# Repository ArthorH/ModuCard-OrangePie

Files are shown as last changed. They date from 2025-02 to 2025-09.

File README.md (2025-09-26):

# ModuCard System Orange PI 5 pro adapter
obraz

## Project Status: **Ongoing**  
### REV C
**Design** ⏳ — **Fabrication** ⏳ — **Assembly** ⏳ — **Bringup** ⏳ — **Testing** ⏳
### REV B
**Design** ✅ — **Fabrication** ✅ — **Assembly** ✅ — **Bringup** ✅ — **Testing** ⛔ 
Failed: https://github.com/ArthorH/ModuCard-OrangePie/issues/6
### REV A
**Design** ✅ — **Fabrication** ✅ — **Assembly** ✅ — **Bringup** ✅ — **Testing** ✅ 
## Key technologies:
&nbsp;&nbsp;&nbsp;&nbsp; &nbsp;&nbsp;&nbsp;&nbsp; &nbsp;&nbsp;&nbsp;&nbsp;
# Features

- 5V 8A psu for Orange PI
- Embedded USB audo interface
- Embedded USB CAN adapter
- External Fan controller
- UART debug interface
  
# Block Diagram
&nbsp;&nbsp;&nbsp;&nbsp;

# Manufactured board


# Moducard OrangePie in Zwentendorf Austria!
AMSModuCard

### Check out other projects

Orange Pie ->  https://github.com/ArthorH/ModuCard-OrangePie

ModuCard Base module -> https://github.com/ArthorH/ModuCard-base-module

ModuCard Backplane -> https://github.com/ArthorH/ModuCard-backplane

ezgif-5062213efaebb7

# Author
Artem Horiunov
# License 
To be added

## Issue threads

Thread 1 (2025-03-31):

Orange hardware issues

X-Lemon-X, 2025-03-31:
- Dodać reset do RPI do  STM od cana i  audio DACa.
- STM brak opużnienia dla właczenia can transceivers ze względu an pin CAN_RX/BOOT0 co powoduje w przejście do  DFU.  takie coć trzeba dodać:
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

Poza tym reszta działa

ArthorH, 2025-05-15:
Do tego układu należy dodać możliwość resetu jest jest triggerowana linia restu stm !!!!

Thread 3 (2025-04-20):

Create layout for fixed schematic

ArthorH, 2025-04-20:

Closed 2025-05-15.

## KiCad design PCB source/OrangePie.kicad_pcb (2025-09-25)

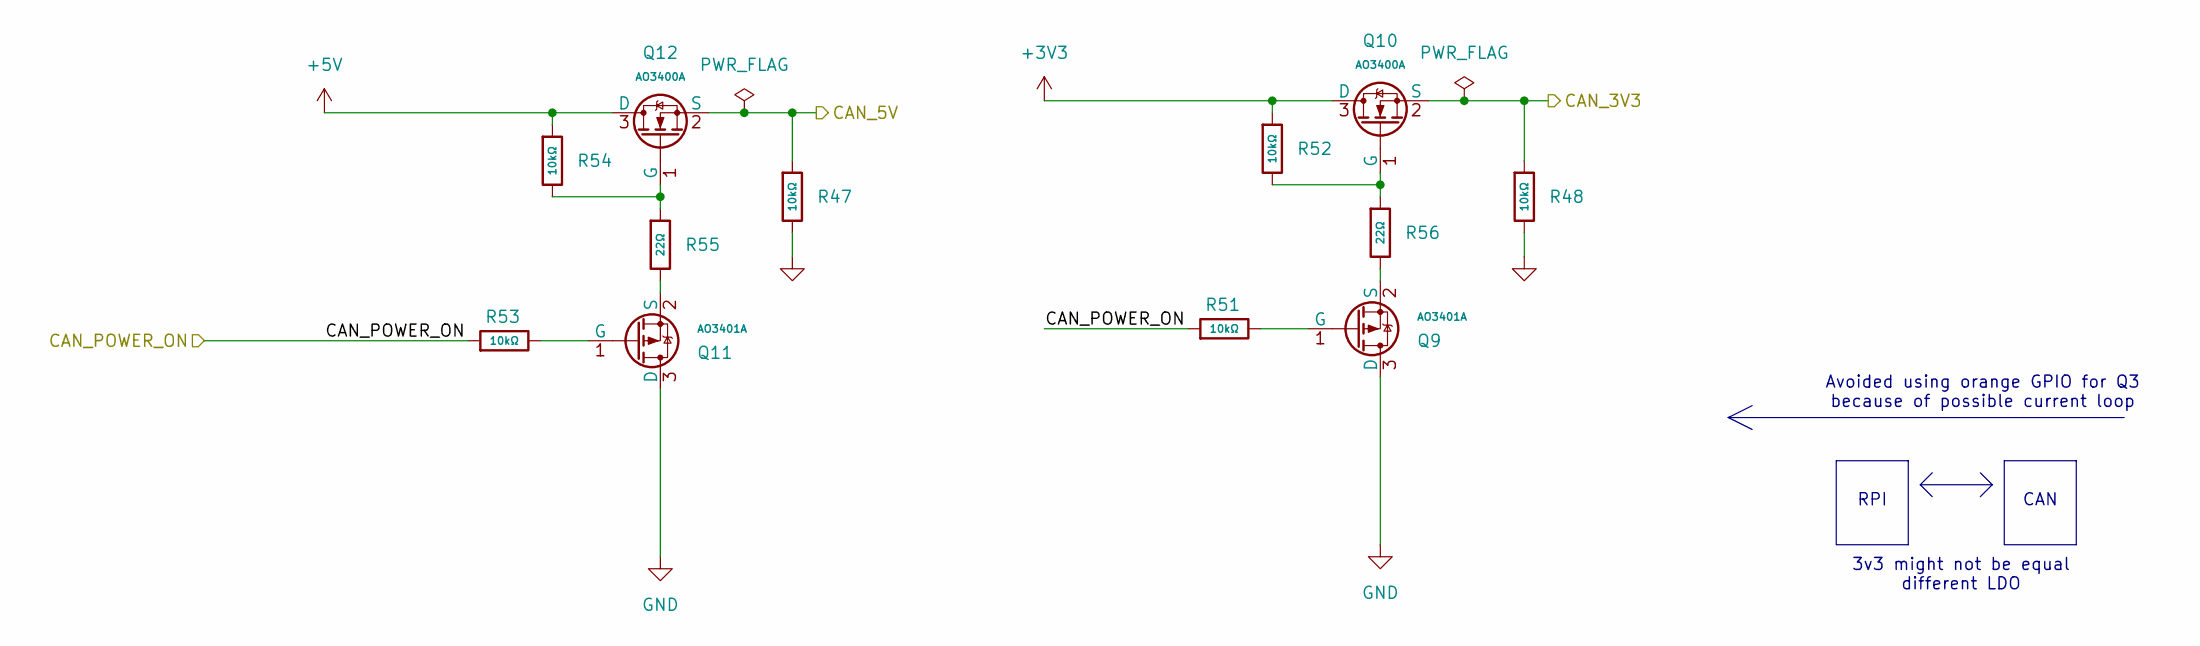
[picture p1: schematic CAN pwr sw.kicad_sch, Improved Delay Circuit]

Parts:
Q9, Q11: AO3401A; Q_SOT-23; Part AO3401A; LCSC C15127
Q10, Q12: AO3400A; Q_SOT-23; Part AO3400A; LCSC C20917
R47, R48, R51, R52, R53, R54: 10kΩ; R_0402; Overload Voltage (Max) 50V; Tolerance ±1%; Part 0402WGF1002TCE; LCSC C25744
R55, R56: 22Ω; R_0402; Overload Voltage (Max) 50V; Tolerance ±1%; Part 0402WGF220JTCE; LCSC C25092

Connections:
+3V3: Q10.3 (D), R52.1; also elsewhere on the board
+5V: Q12.3 (D), R54.1; also elsewhere on the board
/CAN pwr sw/CAN_3V3: Q10.2 (S), R48.1; also elsewhere on the board
/CAN pwr sw/CAN_5V: Q12.2 (S), R47.1; also elsewhere on the board
/CAN pwr sw/CAN_POWER_ON: R51.1, R53.1; also elsewhere on the board
GND: Q9.3 (D), Q11.3 (D), R47.2, R48.2; also elsewhere on the board
unnamed: Q9.1 (G), R51.2
unnamed: Q9.2 (S), R56.2
unnamed: Q10.1 (G), R52.2, R56.1
unnamed: Q11.1 (G), R53.2
unnamed: Q11.2 (S), R55.2
unnamed: Q12.1 (G), R54.2, R55.1

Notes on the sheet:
Avoided using orange GPIO for Q3 because of possible current loop
CAN
RPI
3v3 might not be equal different LDO

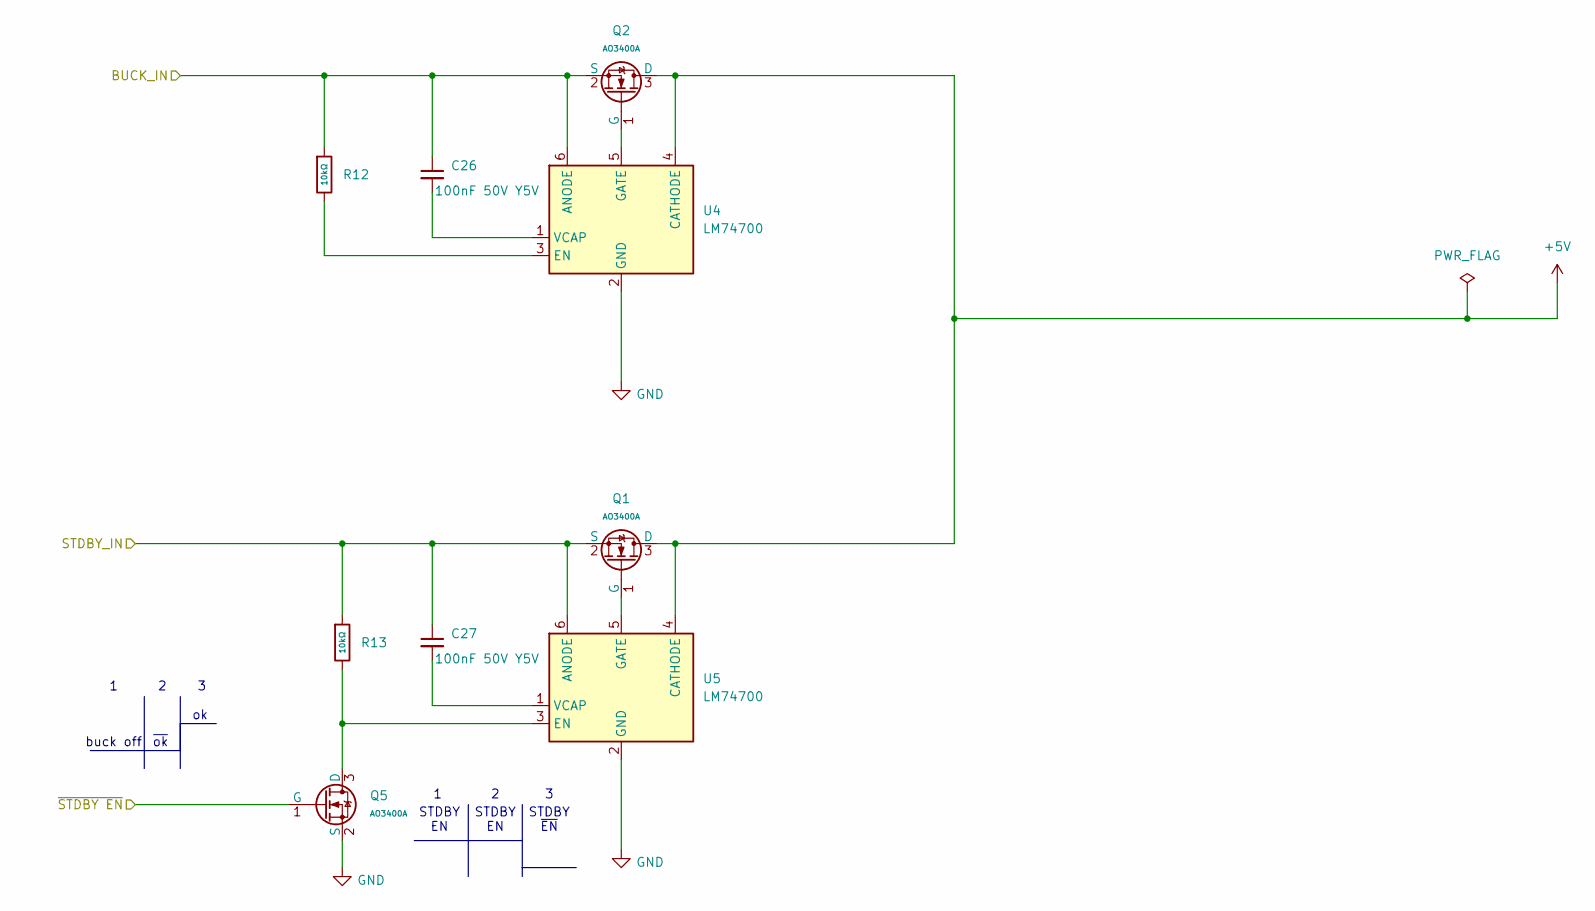
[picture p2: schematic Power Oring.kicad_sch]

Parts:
C26, C27: 100nF 50V Y5V; C_0402_1005Metric
Q1, Q2, Q5: AO3400A; Q_SOT-23; Part AO3400A; LCSC C20917
R12, R13: 10kΩ; R_0402; Overload Voltage (Max) 50V; Tolerance ±1%; Part 0402WGF1002TCE; LCSC C25744
U4, U5: LM74700; SOT-23-6

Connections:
+5V: Q1.3 (D), Q2.3 (D), U4.4 (CATHODE), U5.4 (CATHODE); also elsewhere on the board
/5v buck/BUCK_OUT: C26.1, Q2.2 (S), R12.1, U4.6 (ANODE); also elsewhere on the board
/5v buck/Pgood: Q5.1 (G); also elsewhere on the board
/DIN41612 connector/5v_STDBY: C27.1, Q1.2 (S), R13.1, U5.6 (ANODE); also elsewhere on the board
GND: Q5.2 (S), U4.2 (GND), U5.2 (GND); also elsewhere on the board
unnamed: Q1.1 (G), U5.5 (GATE)
unnamed: Q2.1 (G), U4.5 (GATE)
unnamed: Q5.3 (D), R13.2, U5.3 (EN)
unnamed: R12.2, U4.3 (EN)
unnamed: C26.2, U4.1 (VCAP)
unnamed: C27.2, U5.1 (VCAP)

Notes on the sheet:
buck off
~{ok}
STDBY EN
STDBY ~{EN}

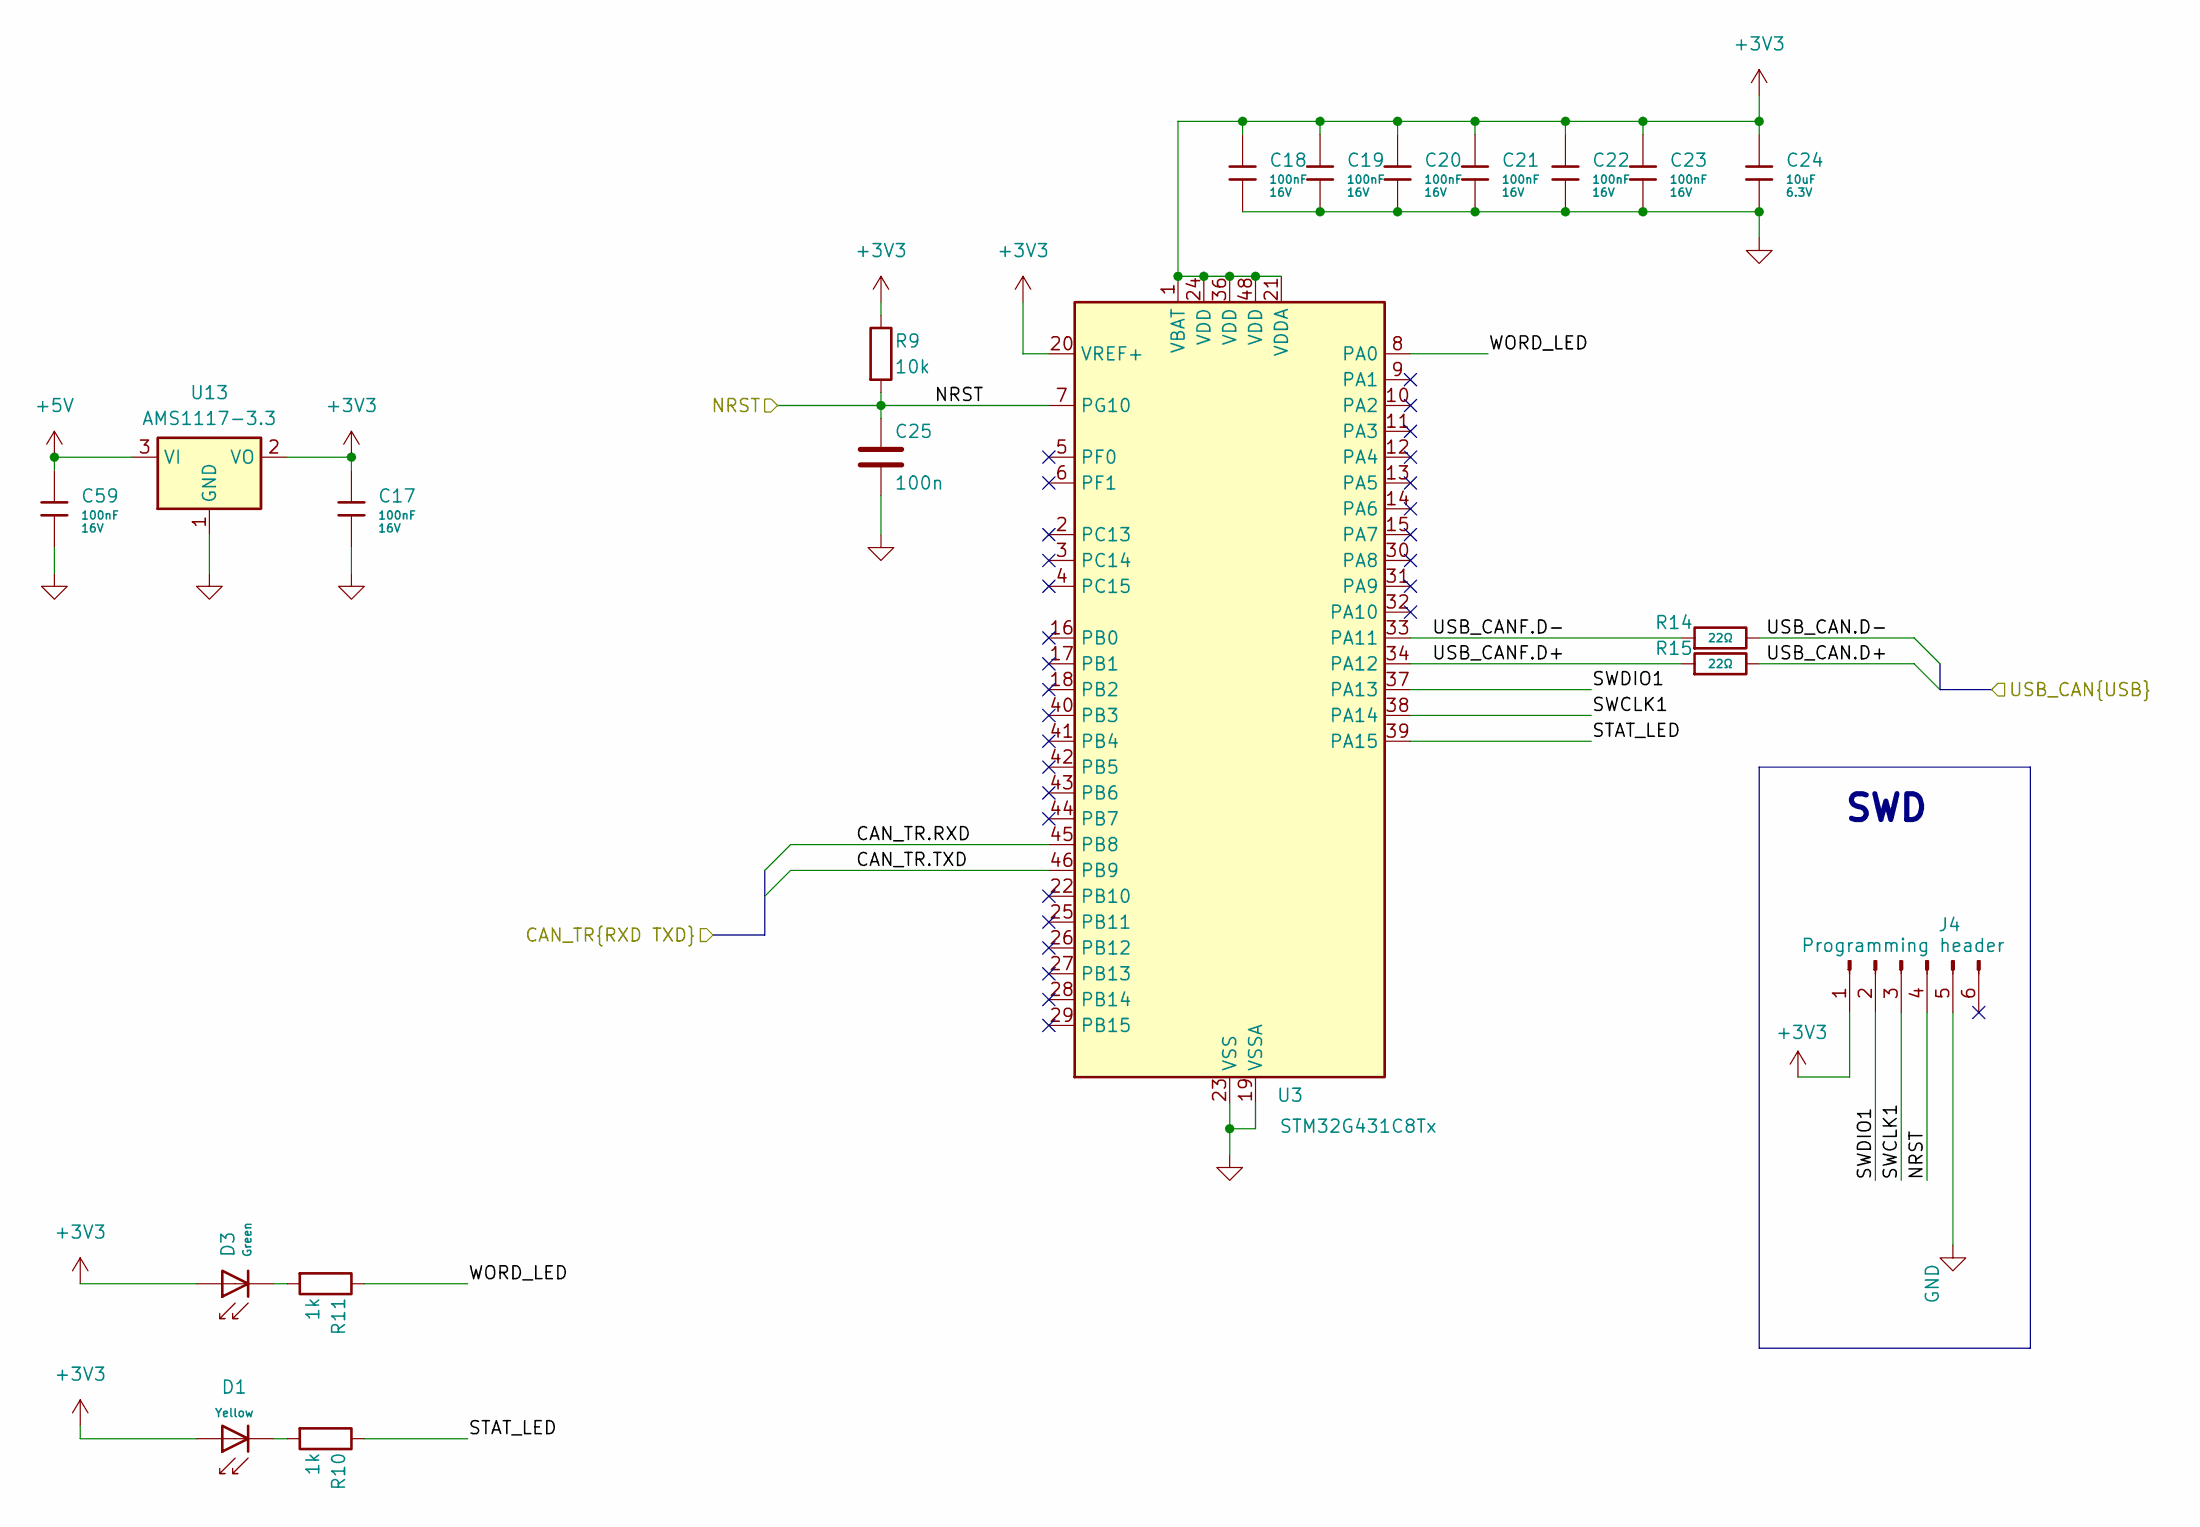
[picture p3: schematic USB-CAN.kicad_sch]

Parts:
C17, C18, C19, C20, C21, C22, C23, C59: 100nF; C_0402; Voltage Rated 16V; Tolerance ±10%; Part CL05B104KO5NNNC; LCSC C1525
C24: 10uF; C_0402; Voltage Rated 6.3V; Tolerance ±20%; Part CL05A106MQ5NUNC; LCSC C15525
C25: 100n; C_0402_1005Metric
D1: Yellow; D_0603; Part 19-213/Y2C-CQ2R2L/3T(CY); LCSC C72038
D3: Green; D_0603; Part 19-217/GHC-YR1S2/6T; LCSC C2986059
J4: Programming header; PinHeader_1x06_P1.27mm_Vertical
R9: 10k; R_0402_1005Metric
R10, R11: 1k; R_0402_1005Metric
R14, R15: 22Ω; R_0402; Overload Voltage (Max) 50V; Tolerance ±1%; Part 0402WGF220JTCE; LCSC C25092
U3: STM32G431C8Tx; LQFP-48_7x7mm_P0.5mm
U13: AMS1117-3.3; SOT-223-3_TabPin2

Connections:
+3V3: C17.1, C18.1, C19.1, C20.1, C21.1, C22.1, C23.1, C24.1, D1.2, D3.2, J4.1, R9.1, U3.1 (VBAT), U3.20 (VREF+), U3.21 (VDDA), U3.24 (VDD), U3.36 (VDD), U3.48 (VDD), U13.2 (VO); also elsewhere on the board
+5V: C59.1, U13.3 (VI); also elsewhere on the board
/Can Transiver1/CAN_TR.RXD: U3.45 (PB8); also elsewhere on the board
/Can Transiver1/CAN_TR.TXD: U3.46 (PB9); also elsewhere on the board
/USB HUB/USB_CAN.D+: R15.2; also elsewhere on the board
/USB HUB/USB_CAN.D-: R14.2; also elsewhere on the board
/USB-CAN/NRST: C25.1, J4.4, R9.2, U3.7 (PG10); also elsewhere on the board
/USB-CAN/STAT_LED: R10.1, U3.39 (PA15)
/USB-CAN/SWCLK1: J4.3, U3.38 (PA14)
/USB-CAN/SWDIO1: J4.2, U3.37 (PA13)
/USB-CAN/USB_CANF.D+: R15.1, U3.34 (PA12)
/USB-CAN/USB_CANF.D-: R14.1, U3.33 (PA11)
/USB-CAN/WORD_LED: R11.1, U3.8 (PA0)
GND: C17.2, C18.2, C19.2, C20.2, C21.2, C22.2, C23.2, C24.2, C25.2, C59.2, J4.5, U3.19 (VSSA), U3.23 (VSS), U3.35 (VSS), U3.47 (VSS), U13.1 (GND); also elsewhere on the board
unnamed: D1.1, R10.2
unnamed: D3.1, R11.2

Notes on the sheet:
SWD

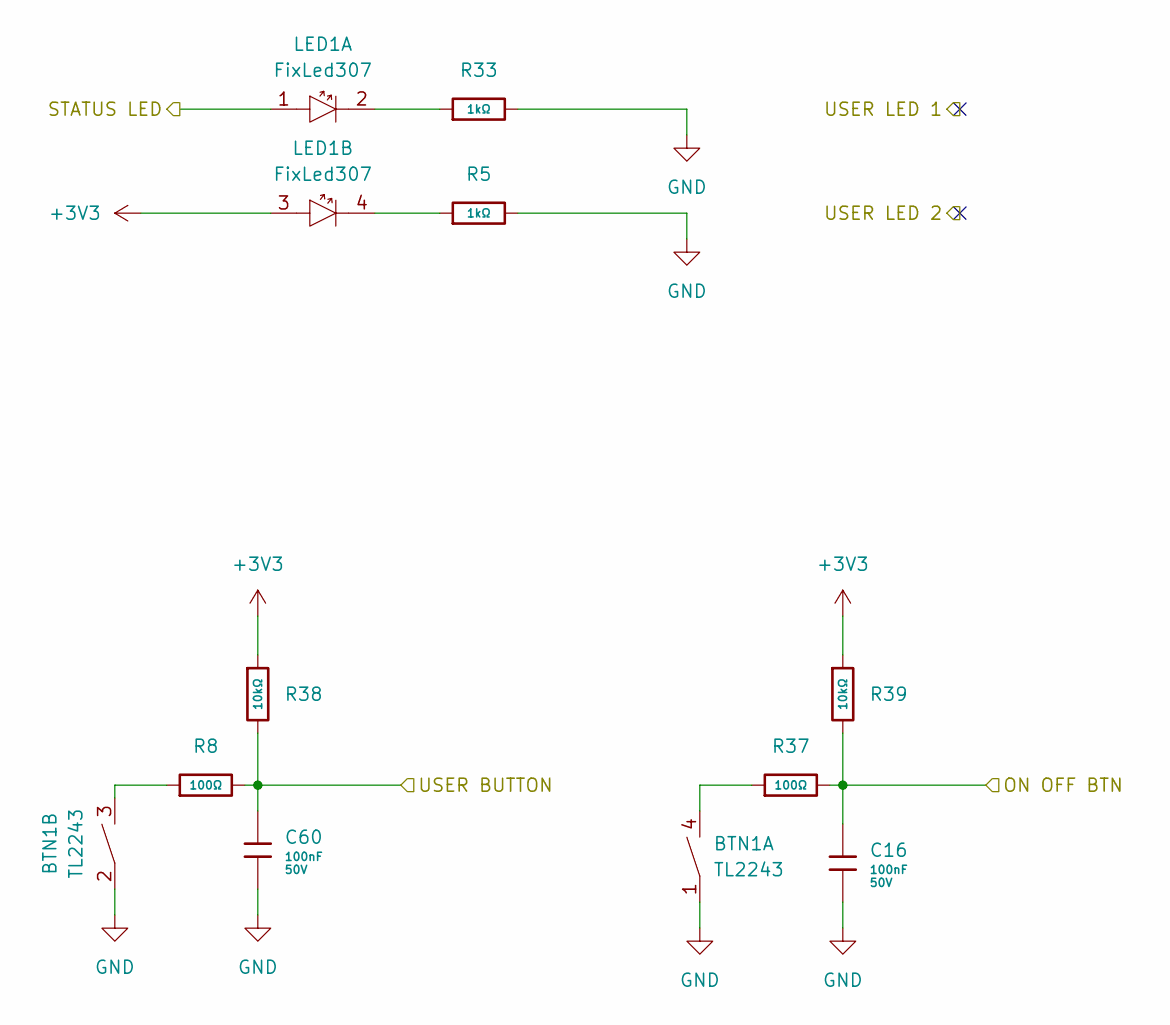
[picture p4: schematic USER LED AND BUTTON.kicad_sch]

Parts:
BTN1: TL2243
C16, C60: 100nF; C_0402; Voltage Rated 50V; Tolerance ±10%; Part CL05B104KB54PNC; LCSC C307331
LED1: FixLed307
R5, R33: 1kΩ; R_0402; Overload Voltage (Max) 50V; Tolerance ±1%; Part 0402WGF1001TCE; LCSC C11702
R8, R37: 100Ω; R_0402; Overload Voltage (Max) 50V; Tolerance ±1%; Part 0402WGF1000TCE; LCSC C25076
R38, R39: 10kΩ; R_0402; Overload Voltage (Max) 50V; Tolerance ±1%; Part 0402WGF1002TCE; LCSC C25744

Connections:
+3V3: LED1.3, R38.1, R39.1; also elsewhere on the board
/OrangePi 5 pro Header/ON OFF BTN: C16.1, R37.2, R39.2; also elsewhere on the board
/OrangePi 5 pro Header/STATUS LED: LED1.1; also elsewhere on the board
/OrangePi 5 pro Header/USER BUTTON: C60.1, R8.2, R38.2; also elsewhere on the board
GND: BTN1.1, BTN1.2, C16.2, C60.2, R5.2, R33.2; also elsewhere on the board
unnamed: BTN1.3, R8.1
unnamed: BTN1.4, R37.1
unnamed: LED1.2, R33.1
unnamed: LED1.4, R5.1

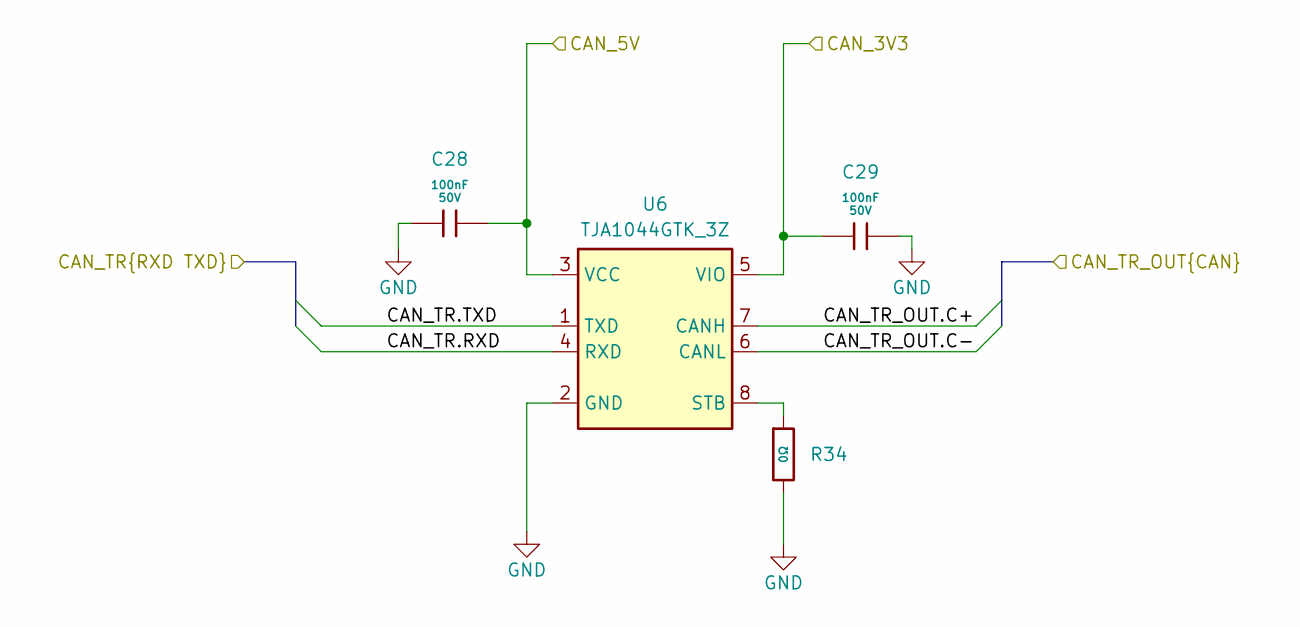
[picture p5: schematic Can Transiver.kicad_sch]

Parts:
C28, C29: 100nF; C_0402; Voltage Rated 50V; Tolerance ±10%; Part CL05B104KB54PNC; LCSC C307331
R34: 0Ω; R_0402; Overload Voltage (Max) 50V; Tolerance ±1%; Part 0402WGF0000TCE; LCSC C17168
U6: TJA1044GTK_3Z; HVSON-8-1EP_3x3mm_P0.65mm_EP1.6x2.4mm; Manufacturer_Part_Number TJA1044GTK/3Z

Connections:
/CAN pwr sw/CAN_3V3: C29.1, U6.5 (VIO); also elsewhere on the board
/CAN pwr sw/CAN_5V: C28.2, U6.3 (VCC); also elsewhere on the board
/Can Transiver/CAN_TR.RXD: U6.4 (RXD); also elsewhere on the board
/Can Transiver/CAN_TR.TXD: U6.1 (TXD); also elsewhere on the board
/Can Transiver/CAN_TR_OUT.C+: U6.7 (CANH); also elsewhere on the board
/Can Transiver/CAN_TR_OUT.C-: U6.6 (CANL); also elsewhere on the board
GND: C28.1, C29.2, R34.2, U6.2 (GND), U6.9 (EP); also elsewhere on the board
unnamed: R34.1, U6.8 (STB)

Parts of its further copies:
C30, C31: 100nF; C_0402; Voltage Rated 50V; Tolerance ±10%; Part CL05B104KB54PNC; LCSC C307331
R35: 0Ω; R_0402; Overload Voltage (Max) 50V; Tolerance ±1%; Part 0402WGF0000TCE; LCSC C17168
U7: TJA1044GTK_3Z; HVSON-8-1EP_3x3mm_P0.65mm_EP1.6x2.4mm; Manufacturer_Part_Number TJA1044GTK/3Z

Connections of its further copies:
/CAN pwr sw/CAN_3V3: C31.1, U7.5 (VIO); also elsewhere on the board
/CAN pwr sw/CAN_5V: C30.2, U7.3 (VCC); also elsewhere on the board
/Can Transiver1/CAN_TR.RXD: U7.4 (RXD); also elsewhere on the board
/Can Transiver1/CAN_TR.TXD: U7.1 (TXD); also elsewhere on the board
/Can Transiver1/CAN_TR_OUT.C+: U7.7 (CANH); also elsewhere on the board
/Can Transiver1/CAN_TR_OUT.C-: U7.6 (CANL); also elsewhere on the board
GND: C30.1, C31.2, R35.2, U7.2 (GND), U7.9 (EP); also elsewhere on the board
unnamed: R35.1, U7.8 (STB)

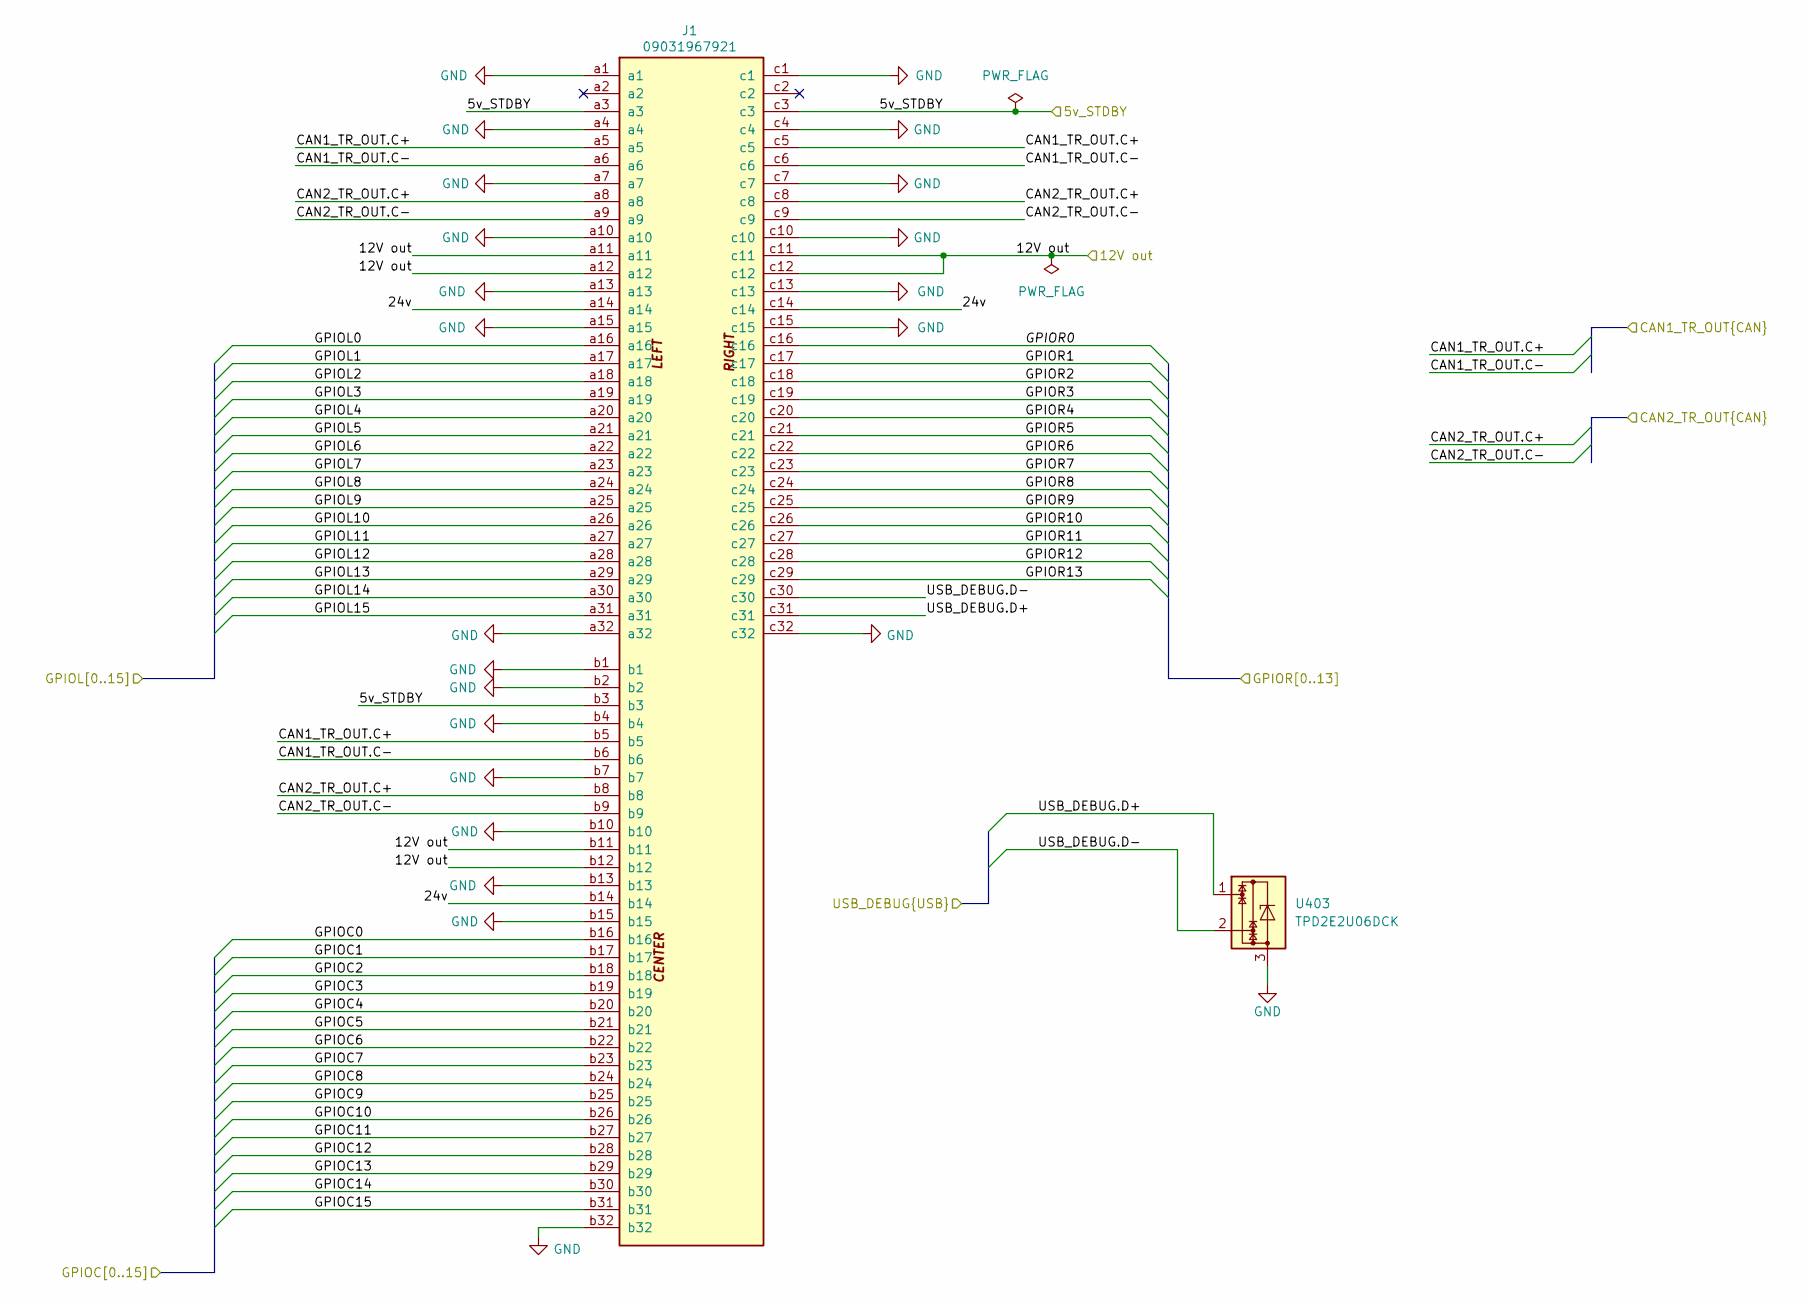
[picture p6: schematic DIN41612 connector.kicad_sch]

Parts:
J1: 09031967921; DIN41612_R_3x32_Female_Horizontal_THT; PARTREV D
U403: TPD2E2U06DCK; SOT-323_SC-70

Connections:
/5v buck/V_{IN}: J1.a11, J1.a12, J1.b11, J1.b12, J1.c11, J1.c12; also elsewhere on the board
/Can Transiver1/CAN_TR_OUT.C+: J1.a8, J1.b8, J1.c8; also elsewhere on the board
/Can Transiver1/CAN_TR_OUT.C-: J1.a9, J1.b9, J1.c9; also elsewhere on the board
/Can Transiver/CAN_TR_OUT.C+: J1.a5, J1.b5, J1.c5; also elsewhere on the board
/Can Transiver/CAN_TR_OUT.C-: J1.a6, J1.b6, J1.c6; also elsewhere on the board
/DIN41612 connector/5v_STDBY: J1.a3, J1.b3, J1.c3; also elsewhere on the board
/DIN41612 connector/24v: J1.a14, J1.b14, J1.c14
/DIN41612 connector/GPIOC0: J1.b16
/DIN41612 connector/GPIOC1: J1.b17
/DIN41612 connector/GPIOC2: J1.b18
/DIN41612 connector/GPIOC3: J1.b19
/DIN41612 connector/GPIOC4: J1.b20
/DIN41612 connector/GPIOC5: J1.b21
/DIN41612 connector/GPIOC6: J1.b22
/DIN41612 connector/GPIOC7: J1.b23
/DIN41612 connector/GPIOC8: J1.b24
/DIN41612 connector/GPIOC9: J1.b25
/DIN41612 connector/GPIOC10: J1.b26
/DIN41612 connector/GPIOC11: J1.b27
/DIN41612 connector/GPIOC12: J1.b28
/DIN41612 connector/GPIOC13: J1.b29
/DIN41612 connector/GPIOC14: J1.b30
/DIN41612 connector/GPIOC15: J1.b31
/DIN41612 connector/GPIOL0: J1.a16
/DIN41612 connector/GPIOL1: J1.a17
/DIN41612 connector/GPIOL2: J1.a18
/DIN41612 connector/GPIOL3: J1.a19
/DIN41612 connector/GPIOL4: J1.a20
/DIN41612 connector/GPIOL5: J1.a21
/DIN41612 connector/GPIOL6: J1.a22
/DIN41612 connector/GPIOL7: J1.a23
/DIN41612 connector/GPIOL8: J1.a24
/DIN41612 connector/GPIOL9: J1.a25
/DIN41612 connector/GPIOL10: J1.a26
/DIN41612 connector/GPIOL11: J1.a27
/DIN41612 connector/GPIOL12: J1.a28
/DIN41612 connector/GPIOL13: J1.a29
/DIN41612 connector/GPIOL14: J1.a30
/DIN41612 connector/GPIOL15: J1.a31
/DIN41612 connector/GPIOR0: J1.c16
/DIN41612 connector/GPIOR1: J1.c17
/DIN41612 connector/GPIOR2: J1.c18
/DIN41612 connector/GPIOR3: J1.c19
/DIN41612 connector/GPIOR4: J1.c20
/DIN41612 connector/GPIOR5: J1.c21
/DIN41612 connector/GPIOR6: J1.c22
/DIN41612 connector/GPIOR7: J1.c23
/DIN41612 connector/GPIOR8: J1.c24
/DIN41612 connector/GPIOR9: J1.c25
/DIN41612 connector/GPIOR10: J1.c26
/DIN41612 connector/GPIOR11: J1.c27
/DIN41612 connector/GPIOR12: J1.c28
/DIN41612 connector/GPIOR13: J1.c29
/DIN41612 connector/USB_DEBUG.D+: J1.c31, U403.1; also elsewhere on the board
/DIN41612 connector/USB_DEBUG.D-: J1.c30, U403.2; also elsewhere on the board
GND: J1.a1, J1.a4, J1.a7, J1.a10, J1.a13, J1.a15, J1.a32, J1.b1, J1.b2, J1.b4, J1.b7, J1.b10, J1.b13, J1.b15, J1.b32, J1.c1, J1.c4, J1.c7, J1.c10, J1.c13, J1.c15, J1.c32, U403.3; also elsewhere on the board

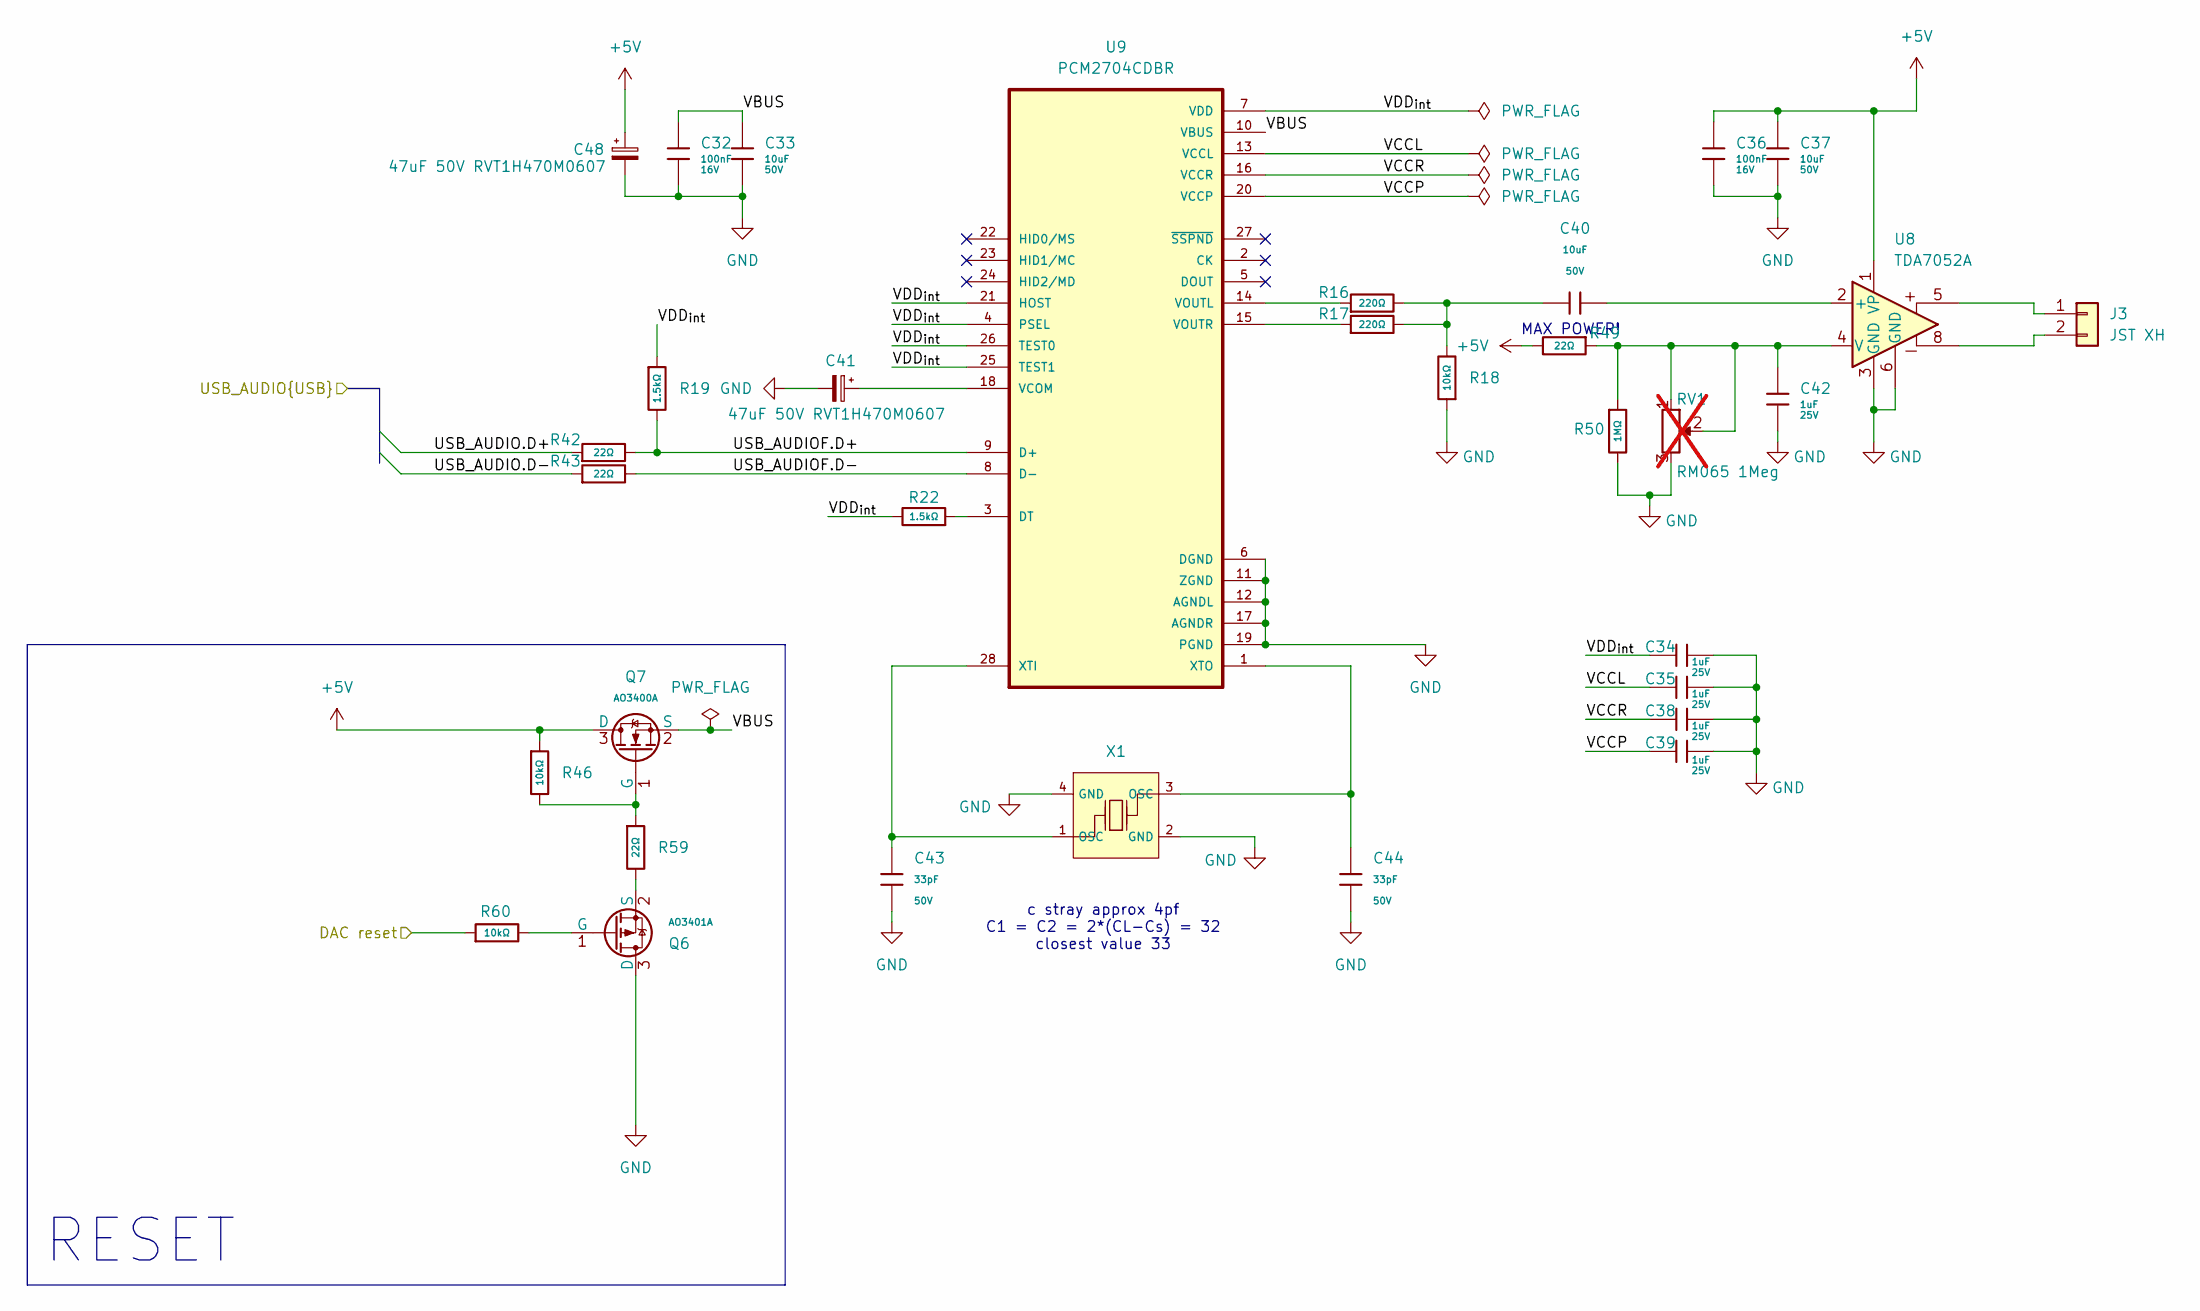
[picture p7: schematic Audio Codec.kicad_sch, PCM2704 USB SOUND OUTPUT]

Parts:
C32, C36: 100nF; C_0402; Voltage Rated 16V; Tolerance ±10%; Part CL05B104KO5NNNC; LCSC C1525
C33, C37, C40: 10uF; C_0805; Voltage Rated 50V; Tolerance ±10%; Part GRM21BR61H106KE43L; LCSC C440198
C34, C35, C38, C39, C42: 1uF; C_0402; Voltage Rated 25V; Tolerance ±10%; Part CL05A105KA5NQNC; LCSC C52923
C41, C48: 47uF 50V RVT1H470M0607; CP_Elec_6.3x7.7
C43, C44: 33pF; C_0402; Voltage Rated 50V; Tolerance ±5%; Part 0402CG330J500NT; LCSC C1562
J3: JST XH; JST_XH_B2B-XH-AM_1x02_P2.50mm_Vertical
Q6: AO3401A; Q_SOT-23; Part AO3401A; LCSC C15127
Q7: AO3400A; Q_SOT-23; Part AO3400A; LCSC C20917
R16, R17: 220Ω; R_0402; Overload Voltage (Max) 50V; Tolerance ±1%; Part 0402WGF2200TCE; LCSC C25091
R18, R46, R60: 10kΩ; R_0402; Overload Voltage (Max) 50V; Tolerance ±1%; Part 0402WGF1002TCE; LCSC C25744
R19, R22: 1.5kΩ; R_0402; Overload Voltage (Max) 50V; Tolerance ±1%; Part 0402WGF1501TCE; LCSC C25867
R42, R43, R49, R59: 22Ω; R_0402; Overload Voltage (Max) 50V; Tolerance ±1%; Part 0402WGF220JTCE; LCSC C25092
R50: 1MΩ; R_0402; Overload Voltage (Max) 50V; Tolerance ±1%; Part 0402WGF1004TCE; LCSC C26083
RV1: RM065 1Meg; Potentiometer_Runtron_RM-065_Vertical; not fitted
U8: TDA7052A; SO-8_3.9x4.9mm_P1.27mm
U9: PCM2704CDBR; SSOP-28_5.3x10.2mm_P0.65mm
X1: X322512MSB4SI; CRYSTAL-SMD_4P-L3.2-W2.5-BL; Frequency Tolerance ±10ppm; Part X322512MSB4SI; LCSC C9002

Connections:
+5V: C36.1, C37.2, C48.1, Q7.3 (D), R46.1, R49.2, U8.1 (VP); also elsewhere on the board
/Audio Codec/DAC reset: R60.1; also elsewhere on the board
/Audio Codec/USB_AUDIO.D+: R42.1; also elsewhere on the board
/Audio Codec/USB_AUDIO.D-: R43.1; also elsewhere on the board
/Audio Codec/USB_AUDIOF.D+: R19.2, R42.2, U9.9 (D+)
/Audio Codec/USB_AUDIOF.D-: R43.2, U9.8 (D-)
/Audio Codec/VBUS: C32.1, C33.2, Q7.2 (S), U9.10 (VBUS)
/Audio Codec/VCCL: C35.1, U9.13 (VCCL)
/Audio Codec/VCCP: C39.1, U9.20 (VCCP)
/Audio Codec/VCCR: C38.1, U9.16 (VCCR)
/Audio Codec/VDD_{int}: C34.1, R19.1, R22.2, U9.4 (PSEL), U9.7 (VDD), U9.21 (HOST), U9.25 (TEST1), U9.26 (TEST0)
GND: C32.2, C33.1, C34.2, C35.2, C36.2, C37.1, C38.2, C39.2, C41.2, C42.2, C43.2, C44.2, C48.2, Q6.3 (D), R18.1, R50.2, RV1.3, U8.3 (GND), U8.6 (GND), U9.6 (DGND), U9.11 (ZGND), U9.12 (AGNDL), U9.17 (AGNDR), U9.19 (PGND), X1.2 (GND), X1.4 (GND); also elsewhere on the board
unnamed: C40.2, R16.2, R17.2, R18.2
unnamed: J3.1, U8.5
unnamed: J3.2, U8.8
unnamed: Q6.1 (G), R60.2
unnamed: Q6.2 (S), R59.2
unnamed: Q7.1 (G), R46.2, R59.1
unnamed: C40.1, U8.2 (+)
unnamed: C42.1, R49.1, R50.1, RV1.1, RV1.2, U8.4 (V)
unnamed: R22.1, U9.3 (DT)
unnamed: C41.1, U9.18 (VCOM)
unnamed: R16.1, U9.14 (VOUTL)
unnamed: R17.1, U9.15 (VOUTR)
unnamed: C43.1, U9.28 (XTI), X1.1 (OSC)
unnamed: C44.1, U9.1 (XTO), X1.3 (OSC)

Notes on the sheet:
RESET
MAX POWER!
c stray approx 4pf C1 = C2 = 2*(CL-Cs) = 32 closest value 33

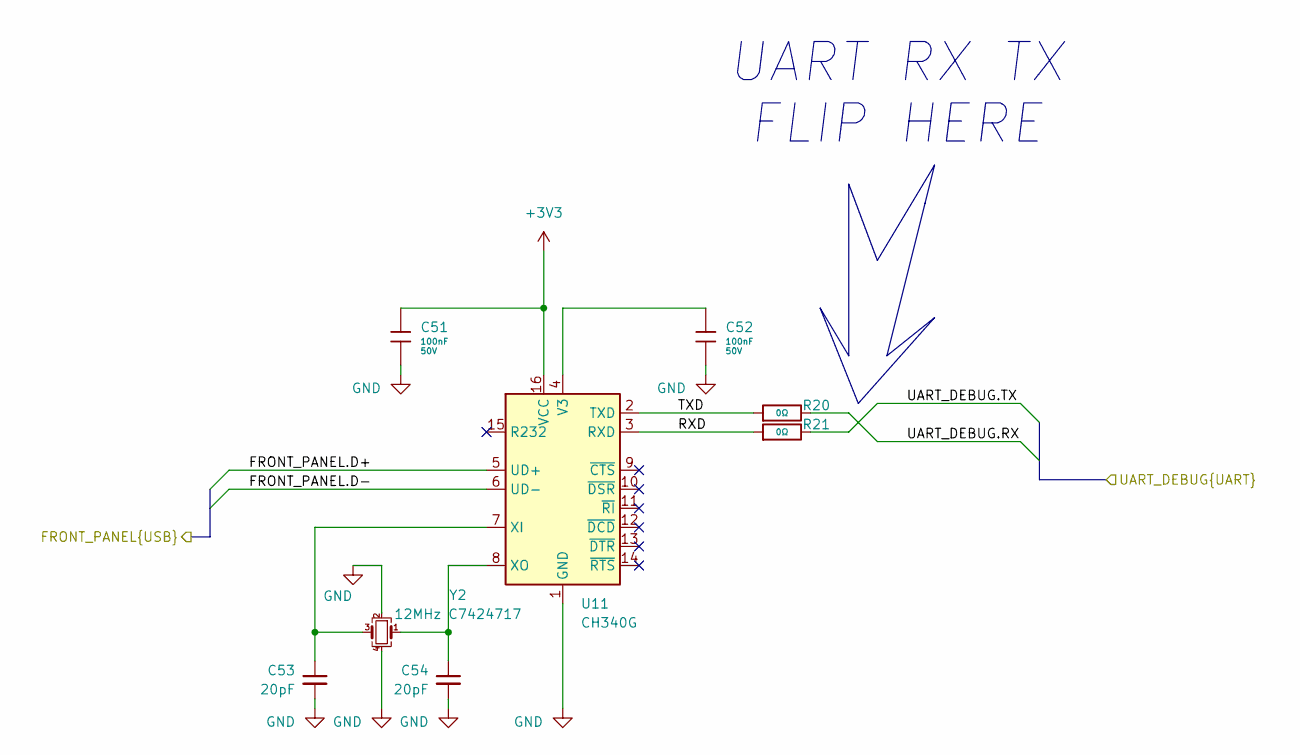
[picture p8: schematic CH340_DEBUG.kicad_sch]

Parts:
C51, C52: 100nF; C_0402; Voltage Rated 50V; Tolerance ±10%; Part CL05B104KB54PNC; LCSC C307331
C53, C54: 20pF; C_0402_1005Metric
R20, R21: 0Ω; R_0402; Overload Voltage (Max) 50V; Tolerance ±1%; Part 0402WGF0000TCE; LCSC C17168
U11: CH340G; SOIC-16_3.9x9.9mm_P1.27mm
Y2: 12MHz C7424717; Crystal_SMD_3225-4Pin_3.2x2.5mm

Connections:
+3V3: C51.1, U11.16 (VCC); also elsewhere on the board
/CH340_DEBUG/FRONT_PANEL.D+: U11.5 (UD+); also elsewhere on the board
/CH340_DEBUG/FRONT_PANEL.D-: U11.6 (UD-); also elsewhere on the board
/CH340_DEBUG/RXD: R21.1, U11.3 (RXD)
/CH340_DEBUG/TXD: R20.1, U11.2 (TXD)
/CH340_DEBUG/UART_DEBUG.RX: R20.2; also elsewhere on the board
/CH340_DEBUG/UART_DEBUG.TX: R21.2; also elsewhere on the board
GND: C51.2, C52.2, C53.2, C54.2, U11.1 (GND), Y2.2, Y2.4; also elsewhere on the board
unnamed: C52.1, U11.4 (V3)
unnamed: C53.1, U11.7 (XI), Y2.3
unnamed: C54.1, U11.8 (XO), Y2.1

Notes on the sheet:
UART RX TX FLIP HERE

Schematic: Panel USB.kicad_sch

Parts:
C55: 100nF; C_0402; Voltage Rated 16V; Tolerance ±10%; Part CL05B104KO5NNNC; LCSC C1525
C56: 10uF; C_0805; Voltage Rated 50V; Tolerance ±10%; Part GRM21BR61H106KE43L; LCSC C440198
J5: USB_C_Receptacle_USB2.0_16P; USB_C_Receptacle_GCT_USB4105-xx-A_16P_TopMnt_Horizontal
R27, R28: 5.1kΩ; R_0402; Overload Voltage (Max) 50V; Tolerance ±1%; Part 0402WGF5101TCE; LCSC C25905
R29, R30: 22Ω; R_0402; Overload Voltage (Max) 50V; Tolerance ±1%; Part 0402WGF220JTCE; LCSC C25092
R31: 1kΩ; R_0402; Overload Voltage (Max) 50V; Tolerance ±1%; Part 0402WGF1001TCE; LCSC C11702
U402: TPD2E2U06DCK; SOT-323_SC-70

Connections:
/CH340_DEBUG/FRONT_PANEL.D+: R30.2, U402.1; also elsewhere on the board
/CH340_DEBUG/FRONT_PANEL.D-: R29.2, U402.2; also elsewhere on the board
/Panel USB/VBUS_IN: C56.1, J5.A4 (VBUS), J5.A9 (VBUS), J5.B4 (VBUS), J5.B9 (VBUS)
GND: C55.2, C56.2, J5.A1 (GND), J5.A12 (GND), J5.B1 (GND), J5.B12 (GND), R27.2, R28.2, R31.2, U402.3; also elsewhere on the board
unnamed: J5.A5 (CC1), R28.1
unnamed: J5.B5 (CC2), R27.1
unnamed: J5.A6 (D+), J5.B6 (D+), R30.1
unnamed: J5.A7 (D-), J5.B7 (D-), R29.1
unnamed: C55.1, J5.S1 (SHIELD), R31.1

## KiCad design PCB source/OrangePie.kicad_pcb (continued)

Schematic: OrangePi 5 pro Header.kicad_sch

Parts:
C6: 10uF; C_1206; Voltage Rated 50V; Tolerance ±10%; Part CL31A106KBHNNNE; LCSC C13585
J2: Orange pi 5 pro; Orange Pi 5 pro
R40: 20kΩ; R_0402; Overload Voltage (Max) 50V; Tolerance ±1%; Part 0402WGF2002TCE; LCSC C25765
R41: 10kΩ; R_0402; Overload Voltage (Max) 50V; Tolerance ±1%; Part 0402WGF1002TCE; LCSC C25744
R44, R45: 22Ω; R_0402; Overload Voltage (Max) 50V; Tolerance ±1%; Part 0402WGF220JTCE; LCSC C25092

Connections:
+5V: C6.1, J2.1 (5V), J2.2 (5V); also elsewhere on the board
/5v buck/Pgood: R40.1; also elsewhere on the board
/Audio Codec/DAC reset: J2.14 (GPIO1_A3/I2C4_SCL/PWM1/SPI4_CS0); also elsewhere on the board
/CAN pwr sw/CAN_POWER_ON: J2.9 (GPIO1_A0/UART6_RX/SPI4_MISO); also elsewhere on the board
/CH340_DEBUG/UART_DEBUG.RX: J2.5 (GPIO0_B6/UART2_RX); also elsewhere on the board
/CH340_DEBUG/UART_DEBUG.TX: J2.4 (GPIO0_B5/UART2_TX); also elsewhere on the board
/Can Transiver/CAN_TR.RXD: J2.35 (GPIO4_B2/PWM14/CAN1_RX); also elsewhere on the board
/Can Transiver/CAN_TR.TXD: J2.34 (GPIO4_B3/PWM15/CAN1_TX); also elsewhere on the board
/DIN41612 connector/USB_DEBUG.D+: R44.2; also elsewhere on the board
/DIN41612 connector/USB_DEBUG.D-: R45.2; also elsewhere on the board
/FAN controller/FAN_PWM: J2.6 (GPIO1_A7/PWM3); also elsewhere on the board
/OrangePi 5 pro Header/ON OFF BTN: J2.26 (GPIO1_A4); also elsewhere on the board
/OrangePi 5 pro Header/STATUS LED: J2.11 (GPIO1_B0); also elsewhere on the board
/OrangePi 5 pro Header/USB_OUT.D+: J2.48 (USB20_DP3); also elsewhere on the board
/OrangePi 5 pro Header/USB_OUT.D-: J2.47 (USB20_DM3); also elsewhere on the board
/OrangePi 5 pro Header/USB_SBCF.D+: J2.43 (USB20_DP4), R44.1
/OrangePi 5 pro Header/USB_SBCF.D-: J2.44 (USB20_DM4), R45.1
/OrangePi 5 pro Header/USER BUTTON: J2.25 (GPIO1_A6); also elsewhere on the board
/OrangePi 5 pro Header/USER LED 1: J2.24 (GPIO1_D7/I2C8_SDA/PWM15)
/OrangePi 5 pro Header/USER LED 2: J2.23 (GPIO4_A7/I2C5_SDA)
/USB-CAN/NRST: J2.27 (GPIO1_A2/SPI4_CLK/PWM0/I2C4_SDA); also elsewhere on the board
GND: C6.2, J2.3 (GND), J2.7 (GND), J2.10 (GND), J2.15 (GND), J2.17 (GND), J2.21 (GND), J2.28 (GND), J2.36 (GND), J2.41 (USB_GND), J2.42 (USB_GND), J2.49 (USB_GND), R41.2; also elsewhere on the board
unnamed: J2.22 (GPIO4_A6/UART3_RX/I2C5_SCL), R40.2, R41.1

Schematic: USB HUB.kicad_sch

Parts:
C45, C47: 10uF; C_0402; Voltage Rated 6.3V; Tolerance ±20%; Part CL05A106MQ5NUNC; LCSC C15525
C46: 1uF; C_0402; Voltage Rated 25V; Tolerance ±10%; Part CL05A105KA5NQNC; LCSC C52923
U10: CH334R; QSOP-16_3.9x4.9mm_P0.635mm
Y1: 12MHz; Crystal_SMD_3225-4Pin_3.2x2.5mm

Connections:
+5V: C47.1, U10.12 (V5); also elsewhere on the board
/Audio Codec/USB_AUDIO.D+: U10.4 (DP3); also elsewhere on the board
/Audio Codec/USB_AUDIO.D-: U10.3 (DM3); also elsewhere on the board
/OrangePi 5 pro Header/USB_OUT.D+: U10.11 (DPU); also elsewhere on the board
/OrangePi 5 pro Header/USB_OUT.D-: U10.10 (DMU); also elsewhere on the board
/USB HUB/USB3.D+: U10.6 (DP2)
/USB HUB/USB3.D-: U10.5 (DM2)
/USB HUB/USB4.D+: U10.8 (DP1)
/USB HUB/USB4.D-: U10.7 (DM1)
/USB HUB/USB_CAN.D+: U10.2 (DP4); also elsewhere on the board
/USB HUB/USB_CAN.D-: U10.1 (DM4); also elsewhere on the board
GND: C45.2, C46.2, C47.2, U10.14 (GND), Y1.2, Y1.4; also elsewhere on the board
unnamed: C45.1, C46.1, U10.13 (VDD33)
unnamed: U10.16 (XI), Y1.1
unnamed: U10.15 (XO), Y1.3

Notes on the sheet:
HUB IC

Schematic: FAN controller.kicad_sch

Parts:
C49: 10uF; C_1206; Voltage Rated 50V; Tolerance ±10%; Part CL31A106KBHNNNE; LCSC C13585
D4: 1N4002W; D_SOD-123FL; Forward Voltage (Vf@If) 1V@1.0A; Reverse Voltage (Vr) 100V; Part 1N4002W; LCSC C18199086
M1: Fan; JST_XH_B2B-XH-AM_1x02_P2.50mm_Vertical
Q4: AO3400A; Q_SOT-23; Part AO3400A; LCSC C20917
R23: 0Ω; R_0402; Overload Voltage (Max) 50V; Tolerance ±1%; Part 0402WGF0000TCE; LCSC C17168
R24: 0Ω; R_0402; Overload Voltage (Max) 50V; Tolerance ±1%; Part 0402WGF0000TCE; LCSC C17168; not fitted
R25: 1.5kΩ; R_0402; Overload Voltage (Max) 50V; Tolerance ±1%; Part 0402WGF1501TCE; LCSC C25867
R26: 10kΩ; R_0402; Overload Voltage (Max) 50V; Tolerance ±1%; Part 0402WGF1002TCE; LCSC C25744

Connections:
+5V: R24.2; also elsewhere on the board
/5v buck/V_{IN}: R23.2; also elsewhere on the board
/FAN controller/FAN_PWM: R25.1; also elsewhere on the board
GND: C49.2, Q4.2 (S), R26.1; also elsewhere on the board
unnamed: C49.1, D4.1, M1.1 (+), R23.1, R24.1
unnamed: D4.2, M1.2 (-), Q4.3 (D)
unnamed: Q4.1 (G), R25.2, R26.2

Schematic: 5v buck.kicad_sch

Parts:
C7, C9, C11: 100nF; C_0402; Voltage Rated 50V; Tolerance ±10%; Part CL05B104KB54PNC; LCSC C307331
C8, C12, C13, C58, C61, C62, C63: 10uF; C_0603; Voltage Rated 10V; Tolerance ±10%; Part CL10A106KP8NNNC; LCSC C19702
C10, C57: 22uF; C_0805; Voltage Rated 25V; Tolerance ±20%; Part CL21A226MAQNNNE; LCSC C45783
C14: 1uF; C_0402; Voltage Rated 25V; Tolerance ±10%; Part CL05A105KA5NQNC; LCSC C52923
C15: 4.7uF; C_0402; Voltage Rated 10V; Tolerance ±20%; Part CL05A475MP5NRNC; LCSC C23733
JP1: Solder Jumper; SolderJumper-2_P1.3mm_Open_RoundedPad1.0x1.5mm
L2: 1uH; L_Bourns_SRP7028A_7.3x6.6mm; MPN CENKER CKST1004-1uH/M-B; LCSC C3002679
R1: 2.2kΩ; R_0402; Overload Voltage (Max) 50V; Tolerance ±1%; Part 0402WGF2201TCE; LCSC C25879
R2, R6: 10kΩ; R_0402; Overload Voltage (Max) 50V; Tolerance ±1%; Part 0402WGF1002TCE; LCSC C25744
R3: 73k2; R_0402; Overload Voltage (Max) 50V; Tolerance ±1%; Part 0402WGF0000TCE; LCSC C17168
R4, R7, R36: 499k; R_0402; Overload Voltage (Max) 50V; Tolerance ±1%; Part 0402WGF0000TCE; LCSC C17168
R32: 20kΩ; R_0402; Overload Voltage (Max) 50V; Tolerance ±1%; Part 0402WGF2002TCE; LCSC C25765
U2: SIC431AED-T1-GE3; REGULATOR_SIC431AED-T1-GE3; MPN SIC431AED-T1-GE3

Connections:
/5v buck/5V_BOOT: C7.1, U2.23 (BOOT)
/5v buck/5V_EN: C9.1, R1.1, R32.2, U2.19 (EN)
/5v buck/5V_FB: R2.1, R3.2, U2.17 (FB)
/5v buck/5V_MODE1: R4.2, R36.1, U2.21 (MODE1)
/5v buck/5V_MODE2: R7.1, U2.20 (MODE2)
/5v buck/5V_OUT: C8.1, C12.1, C13.1, C58.1, C61.1, C62.1, C63.1, JP1.1 (A), L2.2, R3.1, R6.1, U2.18 (V_{OUT})
/5v buck/5V_PHASE: C7.2, U2.24 (PHASE)
/5v buck/5V_SW: L2.1, U2.5 (SW), U2.6 (SW), U2.7 (SW), U2.8 (SW), U2.9 (SW), U2.9.1 (SW)
/5v buck/5V_VDD: C14.1, R4.1, U2.15 (V_{DD})
/5v buck/5V_VDRV: C15.1, U2.12 (V_{DRV})
/5v buck/BUCK_OUT: JP1.2 (B); also elsewhere on the board
/5v buck/Pgood: R6.2, U2.14 (P_{GOOD}); also elsewhere on the board
/5v buck/V_{IN}: C10.1, C11.1, C57.1, R32.1, U2.1 (V_{IN}), U2.2 (V_{IN}), U2.22 (V_{IN}), U2.26 (V_{IN}); also elsewhere on the board
GND: C8.2, C9.2, C10.2, C11.2, C12.2, C13.2, C14.2, C15.2, C57.2, C58.2, C61.2, C62.2, C63.2, R1.2, R2.2, R7.2, R36.2, U2.3 (P_{GND}), U2.4 (P_{GND}), U2.13 (P_{GND}), U2.16 (A_{GND}), U2.25 (A_{GND}), U2.27 (P_{GND}), U2.27_1 (GND), U2.27_2 (GND); also elsewhere on the board

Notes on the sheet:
Sets UVLO to 10.8V
Modified by Artem H for JLCPCB fabhouse capabilities
~{ok}
Copied from ANTMICRO opensource hardware poral check out other designs at https://openhardware.antmicro.com
V_{OUT} = 0.6*(R_{FB_H}+R_{FB_L})/R_{FB_L}
5V @8A
buck off
V_{OUT} = 0.6*(73k2+10k)/10k = 4.992[V]
R_{FB_H} = (R_{FB_L}(V_{OUT}-0.6))/0.6

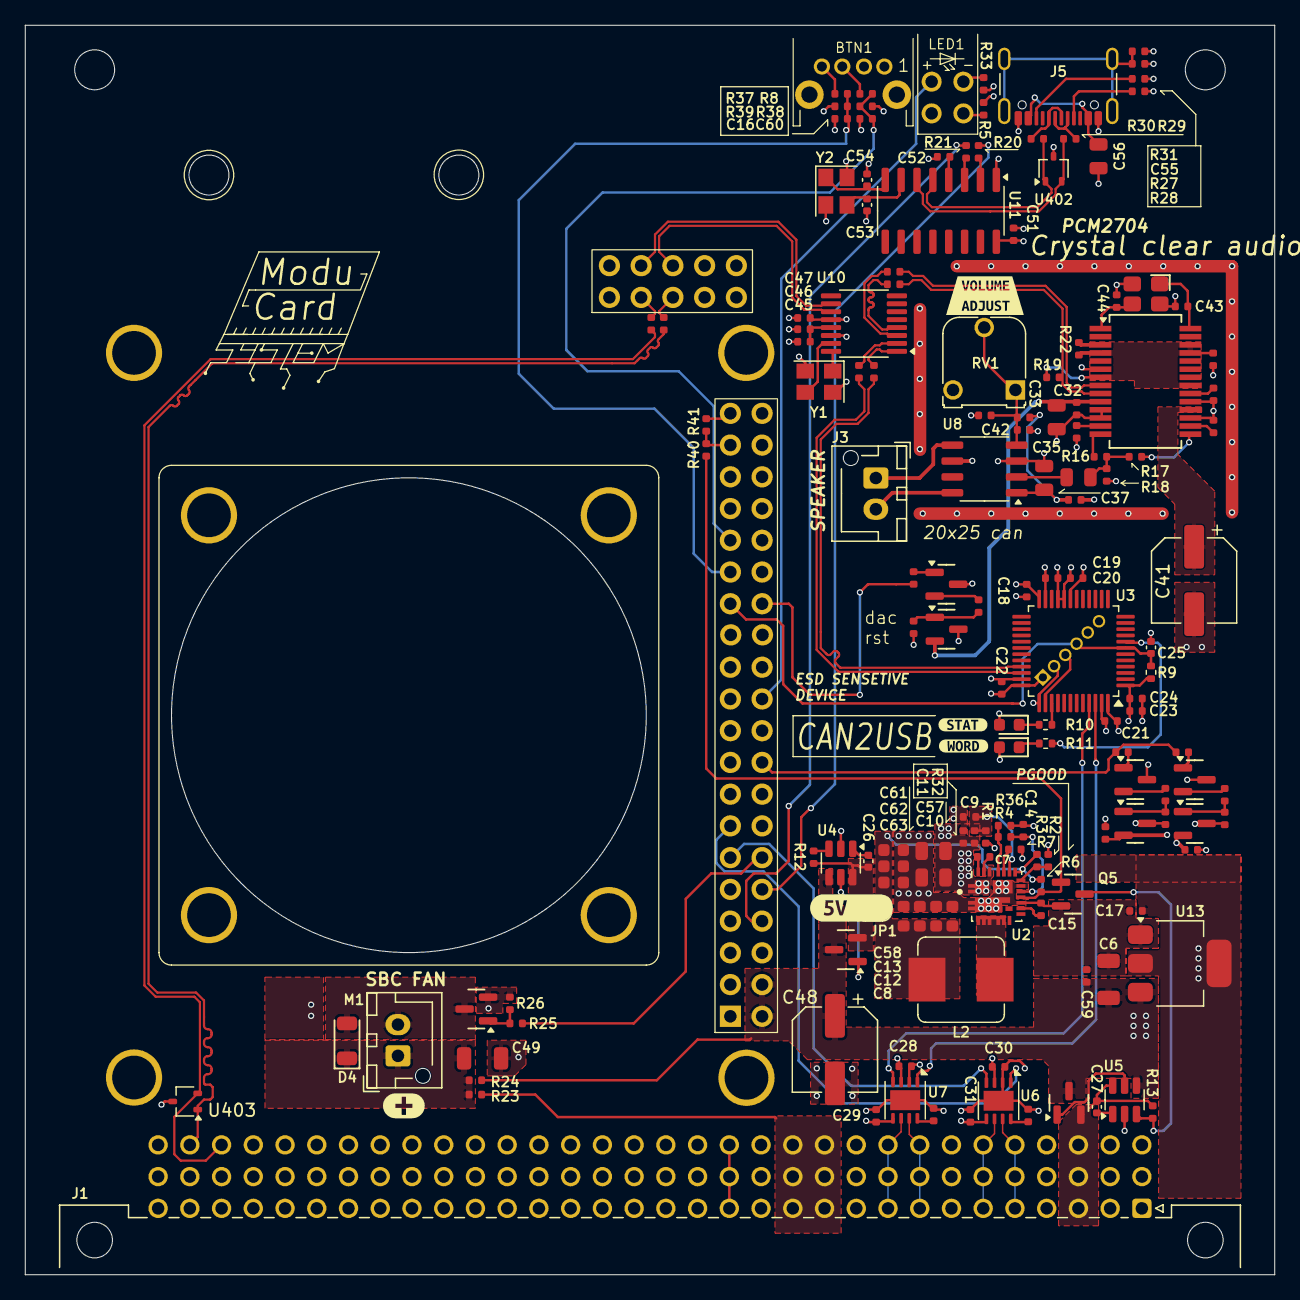
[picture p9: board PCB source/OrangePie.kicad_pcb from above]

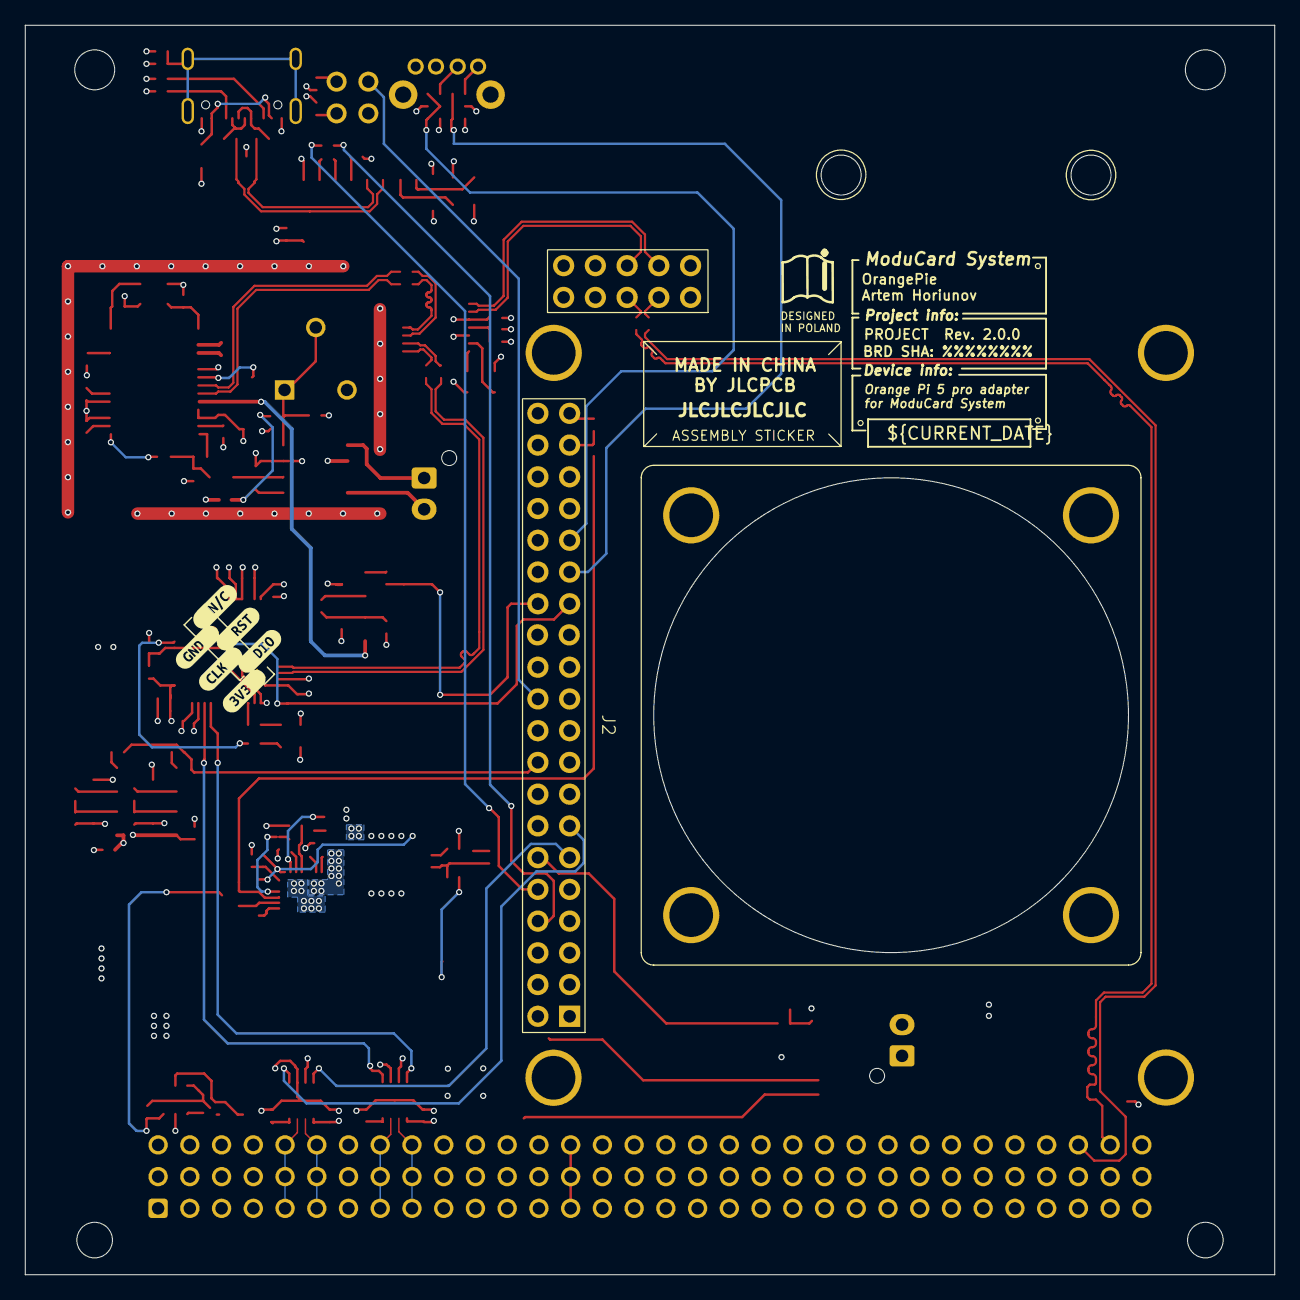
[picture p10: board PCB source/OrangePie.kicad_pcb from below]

Board: 4 copper layers, 100.0 x 100.0 mm, 166 parts (8 on the bottom side), 114 nets.

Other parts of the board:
kibuzzard-67B7B9BD: G***; kibuzzard-67B7B9BD
kibuzzard-67B7B9C6: G***; kibuzzard-67B7B9C6
kibuzzard-67B7BB29: G***; kibuzzard-67B7BB29
kibuzzard-67B7BD37: G***; kibuzzard-67B7BD37
kibuzzard-67B7BFDD: G***; kibuzzard-67B7BFDD
kibuzzard-67B7C21F: G***; kibuzzard-67B7C21F
kibuzzard-67B7C241: G***; kibuzzard-67B7C241
kibuzzard-67B62470: G***; kibuzzard-67B62470
kibuzzard-68D4781A: G***; kibuzzard-68D4781A
kibuzzard-68D47809: G***; kibuzzard-68D47809
kibuzzard-68D47811: G***; kibuzzard-68D47811

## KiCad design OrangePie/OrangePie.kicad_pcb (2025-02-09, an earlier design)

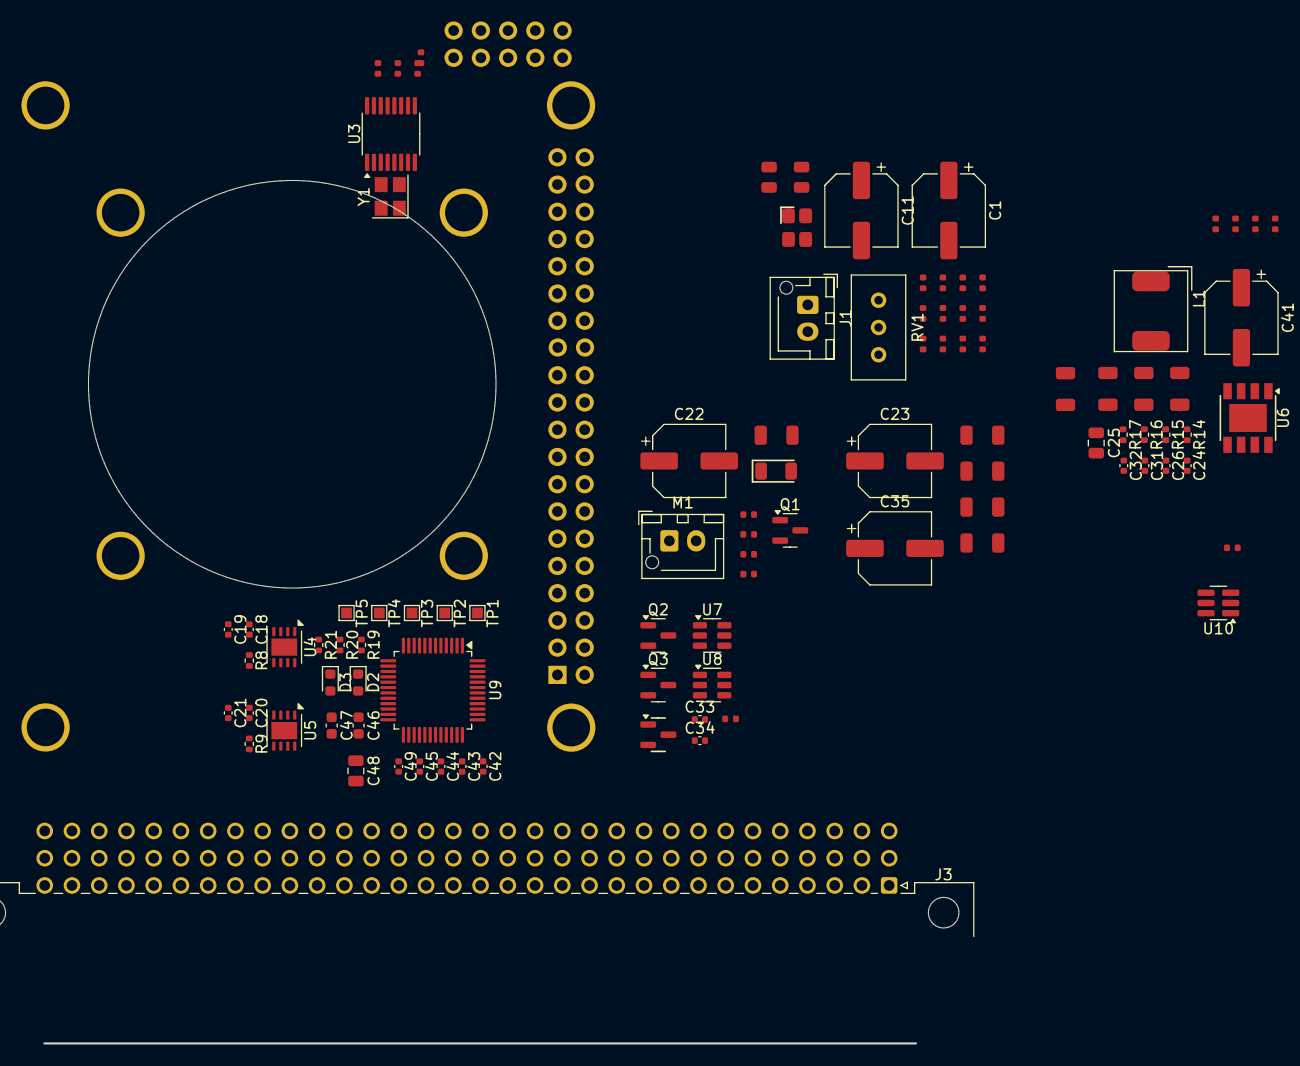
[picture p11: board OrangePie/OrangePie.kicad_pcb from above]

Board: 2 copper layers, 99 parts (1 on the bottom side), 51 nets, no tracks yet.

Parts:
C1, C11, C22, C23, C35, C41: 47uF; CP_Elec_6.3x5.4
C2, C7, C12, C13, C14, C15: 1uF; C_0402
C3, C5: 10uF; C_0805
C4, C6, C17: 100nF; C_0402
C8, C16: 10uF; C_0402
C9, C10: 22pF; C_0402
C18, C19, C20, C21: 100nF; C_0402_1005Metric
C24, C26, C33, C34: 100nF 50V Y5V; C_0402_1005Metric
C25: 10uF 50v; C_0805_2012Metric
C27, C28, C29, C30, C36, C37, C38, C39, C40: 10uF; C_1206
C31, C32: 1uF 25V; C_0402_1005Metric
C42, C43, C44, C45, C49: 100n; C_0402_1005Metric
C46: 1u; C_0603_1608Metric
C47: 4.7u; C_0603_1608Metric
C48: 10u; C_0805_2012Metric
D1: 1N4002W; D_SOD-123FL
D2: WORD_LED; D_0603_1608Metric
D3: STAT_LED; D_0603_1608Metric
J1: JST XH; JST_XH_B2B-XH-AM_1x02_P2.50mm_Vertical
J2: Orange pi 5 pro; Orange Pi 5 pro
J3: 09031967921; DIN41612_R_3x32_Female_Horizontal_THT
L1: 6.8uH 12.5x12.5mm; L_AVX_LMLP07A7
M1: Fan; JST_XH_B2B-XH-AM_1x02_P2.50mm_Vertical
Q1: AO3400A; SOT-23
Q2, Q3: AO3400; SOT-23
Q4: MMBT3904; Q_SOT-23
R1, R2: 220Ω; R_0402
R3, R12, R18, R22: 10kΩ; R_0402
R4, R5, R13: 1.5kΩ; R_0402
R6, R7: 22Ω; R_0402
R8, R9, R19: 10k; R_0402_1005Metric
R10, R11: 0Ω; R_0402
R14: 39k 1%; R_0402_1005Metric
R15: 31.6k 1%; R_0402_1005Metric
R16, R17: 10k 1%; R_0402_1005Metric
R20, R21: 1k; R_0402_1005Metric
RV1: 1Meg Bourns 3296; Potentiometer_Bourns_3296W_Vertical
TP1, TP2, TP3, TP4, TP5: TestPoint_Pad_1.0x1.0mm
U3: CH334R; QSOP-16_3.9x4.9mm_P0.635mm
U4, U5: TJA1044GTK_3Z; HVSON-8-1EP_3x3mm_P0.65mm_EP1.6x2.4mm
U6: Diodes_SO-8EP
U7, U8: LM74700; SOT-23-6
U9: STM32G431C8Tx; LQFP-48_7x7mm_P0.5mm
U10: IP4234CZ6,115; SC-74-6_1.55x2.9mm_P0.95mm
X1: X322512MSB4SI; CRYSTAL-SMD_4P-L3.2-W2.5-BL
Y1: 12MHz; Crystal_SMD_3225-4Pin_3.2x2.5mm

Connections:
+3V3: C19.2, C21.2, C42.1, C43.1, C44.1, C45.1, C46.1, C47.1, C48.1, D2.2 (A), D3.2 (A), J2.32 (3V3), J2.40 (3V3), R19.1, TP1.1, U4.5 (VIO), U5.5 (VIO), U9.1 (VBAT), U9.20 (VREF+), U9.21 (VDDA), U9.24 (VDD), U9.36 (VDD), U9.48 (VDD)
+5V: C3.2, C4.1, C5.2, C6.1, C16.1, C17.1, C18.2, C20.2, C23.1, C35.1, C36.1, C37.1, C38.1, C39.1, J2.1 (5V), J2.2 (5V), Q2.2 (D), Q3.2 (D), R4.2, R5.1, R11.2, U3.12 (V5), U4.3 (VCC), U5.3 (VCC), U7.4 (CATHODE), U8.4 (CATHODE)
+12V: J3.b11, J3.b12, R10.2
/5v buck/5V_OUT: C27.1, C28.1, C29.1, C30.1, C33.1, L1.2, Q2.3 (S), Q4.1 (B), R15.1, R18.1, U7.6 (ANODE)
/Audio Codec/USB_AUDIO.+: R5.2, R6.1, U3.2 (DP4)
/Audio Codec/USB_AUDIO.-: R7.1, U3.1 (DM4)
/Can Transiver1/CAN_TR.RXD: U5.4 (RXD), U9.45 (PB8)
/Can Transiver1/CAN_TR.TXD: U5.1 (TXD), U9.46 (PB9)
/DIN41612 connector/5v_STDBY: C34.1, J3.a3, J3.c3, Q3.3 (S), R22.1, U8.6 (ANODE)
/DIN41612 connector/12v: C25.1, C26.1, C41.1, J3.a11, J3.a12, J3.c11, J3.c12, R14.1, U6.7 (Vin), U6.8 (Vin)
/DIN41612 connector/24v: J3.a14, J3.c14
/DIN41612 connector/CAN1..+: J3.b5, J3.c5
/DIN41612 connector/CAN1..-: J3.b6, J3.c6
/DIN41612 connector/CAN2..+: J3.b8, J3.c8
/DIN41612 connector/CAN2..-: J3.b9, J3.c9
/DIN41612 connector/USB1U.D+: J3.a2, U10.4, U10.6
/DIN41612 connector/USB1U.D-: J3.c2, U10.1, U10.3
/USB HUB/USB_CAN.+: U3.4 (DP3), U9.34 (PA12)
/USB HUB/USB_CAN.-: U3.3 (DM3), U9.33 (PA11)
/USB-CAN/NRST1: C49.1, R19.2, TP2.1, U9.7 (PG10)
/USB-CAN/STAT_LED1: R21.1, U9.39 (PA15)
/USB-CAN/SWCLK1: TP4.1, U9.38 (PA14)
/USB-CAN/SWDIO1: TP3.1, U9.37 (PA13)
/USB-CAN/WORD_LED1: R20.1, U9.8 (PA0)
GND: C1.2, C2.2, C3.1, C4.2, C5.1, C6.2, C7.2, C8.2, C9.2, C10.2, C12.2, C13.2, C14.2, C15.2, C16.2, C17.2, C18.1, C19.1, C20.1, C21.1, C22.2, C23.2, C25.2, C26.2, C27.2, C28.2, C29.2, C30.2, C31.1, C32.1, C35.2, C36.2, C37.2, C38.2, C39.2, C40.2, C41.2, C42.2, C43.2, C44.2, C45.2, C46.2, C47.2, C48.2, C49.2, J2.3 (GND), J2.7 (GND), J2.10 (GND), J2.15 (GND), J2.17 (GND), J2.21 (GND), J2.28 (GND), J2.36 (GND), J2.41 (USB_GND), J2.42 (USB_GND), J2.49 (USB_GND), J3.a1, J3.a4, J3.a7, J3.a10, J3.a13, J3.a15, J3.a32, J3.b1, J3.b2, J3.b4, J3.b7, J3.b10, J3.b13, J3.b15, J3.b32, J3.c1, J3.c4, J3.c7, J3.c10, J3.c13, J3.c15, J3.c32, Q1.2 (S), Q4.2 (E), R3.1, R8.1, R9.1, R12.1, R16.2, R17.2, RV1.3, TP5.1, U3.14 (GND), U4.2 (GND), U4.9 (EP), U5.2 (GND), U5.9 (EP), U6.9 (EPAD), U7.2 (GND), U8.2 (GND), U9.19 (VSSA), U9.23 (VSS), U9.35 (VSS), U9.47 (VSS), X1.2 (GND), X1.4 (GND), Y1.2, Y1.4
unnamed: C11.1, R1.2, R2.2, R3.2
unnamed: D2.1 (K), R20.2
unnamed: D3.1 (K), R21.2
unnamed: C22.1, C40.1, D1.1, M1.1 (+), R10.1, R11.1
unnamed: D1.2, M1.2 (-), Q1.3 (D)
unnamed: Q1.1 (G), R12.2, R13.2
unnamed: Q2.1 (G), U7.5 (GATE)
unnamed: Q3.1 (G), U8.5 (GATE)
unnamed: Q4.3 (C), R18.2, U7.3 (EN)
unnamed: C10.1, X1.1 (OSC)
unnamed: C9.1, X1.3 (OSC)
unnamed: C2.1, RV1.1, RV1.2
unnamed: C7.1, C8.1, U3.13 (VDD33)
unnamed: U3.16 (XI), Y1.1
unnamed: U3.15 (XO), Y1.3
unnamed: R8.2, U4.8 (STB)
unnamed: R9.2, U5.8 (STB)
unnamed: C24.1, U6.1 (BST)
unnamed: R14.2, R16.1, U6.3 (EN)
unnamed: R15.2, R17.1, U6.5 (FB)
unnamed: C24.2, L1.1, U6.2 (Lx)
unnamed: C32.2, U6.4 (SS)
unnamed: C31.2, U6.6 (VCC)
unnamed: C33.2, U7.1 (VCAP)
unnamed: R22.2, U8.3 (EN)
unnamed: C34.2, U8.1 (VCAP)

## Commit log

2025-02-08 Add base schematic and PCM audio interface
    [5v buck.kicad_sch, Audio Codec.kicad_sch, Can Transiver.kicad_sch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]
2025-02-08 Add usb hub and can tranceiver
    [Audio Codec.kicad_sch, Can Transiver.kicad_sch, OrangePie.kicad_sch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]
2025-02-09 Update rest of schematic
    [5v buck.kicad_sch, Can Transiver.kicad_sch, DIN41612 connector.kicad_sch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]
2025-02-10 Add CH340 debug
    [5v buck.kicad_sch, Audio Codec.kicad_sch, CH340_DEBUG.kicad_sch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]
2025-02-15 Do Cleanup
    [5v buck.kicad_sch, Audio Codec.kicad_sch, CH340_DEBUG.kicad_sch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]
2025-02-15 Fix audio codec schematic
    [Audio Codec.kicad_sch]
2025-02-15 Figure out SSPND pin
    [Audio Codec.kicad_sch, OrangePie.kicad_pcb]
2025-02-15 Pass ERC
    [5v buck.kicad_sch, CH340_DEBUG.kicad_sch, DIN41612 connector.kicad_sch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]
2025-02-15 Prepare board for layout
    [5v buck.kicad_sch, Audio Codec.kicad_sch, CH340_DEBUG.kicad_sch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]
2025-02-16 Do buck Layout
    [5v buck.kicad_sch, Audio Codec.kicad_sch, CH340_DEBUG.kicad_sch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]
2025-02-18 Create v1 floorplan
    [Audio Codec.kicad_sch, OrangePi 5 pro Header.kicad_sch, OrangePie.kicad_pcb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]
2025-02-20 Do signal layer layout
    [DIN41612 connector.kicad_sch, OrangePie.kicad_pcb, Panel USB.kicad_sch]
2025-02-20 Finish layout
    [OrangePie.kicad_pcb, Panel USB.kicad_sch, USB HUB.kicad_sch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]
2025-02-20 Add silk
    [OrangePie.kicad_pcb]
2025-02-20 Change speaker holes position
    [OrangePie.kicad_pcb]
2025-02-21 Prepare for boardhouse
    [OrangePie-CuBottom.gbr, OrangePie-CuIn1.gbr, OrangePie-CuIn2.gbr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]
2025-02-21 Add 22R resistors to USB
    [Audio Codec.kicad_sch, Can Transiver.kicad_sch, OrangePi 5 pro Header.kicad_sch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]
2025-02-21 Check BOM and add tooling holes
    [OrangePie-CuBottom.gbr, OrangePie-CuIn1.gbr, OrangePie-CuIn2.gbr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]
2025-02-22 Make ready for fabrication
    [OrangePie-CuBottom.gbr, OrangePie-CuIn1.gbr, OrangePie-CuIn2.gbr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]
2025-04-20 Fix schematic
    [5v buck.kicad_sch, Audio Codec.kicad_sch, CAN pwr sw.kicad_sch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]
2025-04-20 [3] Start layout
    [Audio Codec.kicad_sch, FAN controller.kicad_sch, OrangePie.kicad_pcb]
2025-04-20 [3] Finish pcb
    [Audio Codec.kicad_sch, OrangePie.kicad_pcb, Power Oring.kicad_sch]
2025-04-20 Bump revision
    [OrangePie.kicad_pcb]
2025-04-20 [3] Bump revision
    [OrangePie.kicad_pcb]
2025-05-24 production ready
    [Audio Codec.kicad_sch, CAN pwr sw.kicad_sch, OrangePi 5 pro Header.kicad_sch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]
2025-09-24 Fix can power delivery , fixed placment of the mosfets, CAN power pull down to avoid DFU boot, added new porgraming connector
    [Audio Codec.kicad_sch, CAN pwr sw.kicad_sch, Can Transiver.kicad_sch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]

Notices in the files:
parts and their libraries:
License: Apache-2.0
